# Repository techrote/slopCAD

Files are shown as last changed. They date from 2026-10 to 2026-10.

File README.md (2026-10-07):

# slopCAD

A small collection of practical CAD experiments and 3D-printable workshop parts.

## Contents

- [Hex bit stand](projects/hex-bit-stand/) — compact organizers for 1/4-inch hex bits, developed through several iterations.
  - [v1 — 16-pocket grid](projects/hex-bit-stand/v1-grid-16/)
  - [v2 — 13-pocket hex pattern](projects/hex-bit-stand/v2-hex-pattern-13/)
  - [v3 — 13-pocket contoured body](projects/hex-bit-stand/v3-contoured-13/)
  - [v4 — dense 51-pocket stand](projects/hex-bit-stand/v4-dense-51/) — high-capacity version
  - [v5 — dense contoured 13-pocket stand](projects/hex-bit-stand/v5-dense-contoured-13/) — compact vertical-pocket version
  - [v6 — outward-tilted dense 13-pocket stand](projects/hex-bit-stand/v6-outward-tilted-13/) — 12 outer pockets splayed 10°
  - [v7 — material-efficient dense 51-pocket stand](projects/hex-bit-stand/v7-material-efficient-51/) — relieved pocket floors and tapered wall panels
  - [v8 — tiered-tilt 19-pocket stand](projects/hex-bit-stand/v8-tiered-tilt-19/) — centre vertical, inner ring 4°, outer ring 8°
  - [v9 — effect-plate tiered-tilt 19-pocket stand](projects/hex-bit-stand/v9-effect-plate-19/) — universal misaligned chamfers, inset wall panels, and round floor reliefs
  - [v10 — tapered-hex-floor effect-plate 19-pocket stand](projects/hex-bit-stand/v10-effect-plate-hex-floor-19/) — corrected centre lead-in and 55° tapered hex floor reliefs
  - [v11 — tiered-tilt 37-pocket stand](projects/hex-bit-stand/v11-tiered-tilt-37/) — adds an 18-pocket outer ring at 12°
  - [v12 — clean-wall tiered-tilt 37-pocket stand](projects/hex-bit-stand/v12-clean-wall-37/) — convex 24-face shell removes short-facet triangular print artifacts
  - [v13 — lip-edge panel 37-pocket stand](projects/hex-bit-stand/v13-lip-edge-panels-37/) — wall recesses run directly down to the lower lip
  - [v14 — tiered-tilt 61-pocket stand](projects/hex-bit-stand/v14-tiered-tilt-61/) — historical misaligned-mouth 16° outer-ring experiment
  - [v15 — continuous-web 61-pocket stand](projects/hex-bit-stand/v15-continuous-web-61/) — aligned entrances, measured 1.3 mm minimum surface-web rule and test coupon
  - [v16 — continuous-web 91-pocket stand](projects/hex-bit-stand/v16-continuous-web-91/) — adds a 30-pocket 20° ring; 9.45 mm pitch
  - [v17 — continuous-web 127-pocket stand](projects/hex-bit-stand/v17-continuous-web-127/) — adds a 36-pocket 24° ring; 9.65 mm pitch
  - [v18 — continuous-web 169-pocket stand](projects/hex-bit-stand/v18-continuous-web-169/) — adds a 42-pocket 28° ring; 9.90 mm pitch
  - [v19 — continuous-web 217-pocket stand](projects/hex-bit-stand/v19-continuous-web-217/) — adds a 48-pocket 32° ring; 10.20 mm pitch
  - [v20 — continuous-web 271-pocket stand](projects/hex-bit-stand/v20-continuous-web-271/) — adds a 54-pocket 36° ring; 10.55 mm pitch and wider outer wall
- [Hex handles](project/hex-handles/) — compact five-rib tool handles with deep hex-shaft reinforcement, epoxy retention pockets, and tail venting.
  - [v1 — 32 mm five-rib angular handle](project/hex-handles/v1-32mm-five-rib/) — 6.4 mm AF socket for a nominal 26 mm embedded hex shaft
- [Hex bit stand design history](docs/hex-bit-stand-design-history.md)
- [Current printing and minimum-feature rules](docs/printing.md)
- [Hex handle design history](docs/hex-handles-design-history.md)
- [Hex handle printing and installation notes](docs/hex-handles-printing.md)

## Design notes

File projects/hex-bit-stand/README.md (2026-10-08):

# Hex bit stand

A family of workshop organizers for standard 1/4-inch hex driver bits, developed through printed prototypes.

## Current design target

Functional pockets are **7.0 mm AF normal to the bit axis**, with **12 mm main pocket depth** and a **0.6 mm nozzle** as the primary FDM target. New top/bottom faces must retain **at least 1.3 mm of actual solid ligament** after all cuts, projections and chamfers. Read [the current design/printing rules](../../docs/printing.md); historical thin-web variants are not certified against this newer minimum.

## Versions

| Version | Capacity | Layout | Main change |
|---|---:|---|---|
| [v1](v1-grid-16/) | 16 | 4 × 4 grid | Initial rectangular stand |
| [v2](v2-hex-pattern-13/) | 13 | 4–5–4 | Staggered hex-pocket layout and 1 mm base |
| [v3](v3-contoured-13/) | 13 | 4–5–4 | Body follows the pocket cluster; faceted outer-wall styling |
| [v4](v4-dense-51/) | 51 | 6–7–8–9–8–7–6 | Dense honeycomb packing and high capacity |
| [v5](v5-dense-contoured-13/) | 13 | dense 4–5–4 | Compact v3-style stand using v4 pocket spacing and softened lower lip |
| [v6](v6-outward-tilted-13/) | 13 | dense 4–5–4 | Centre pocket vertical; 12 outer pockets tilted 10° outward |
| [v7](v7-material-efficient-51/) | 51 | 6–7–8–9–8–7–6 | 5.6 mm floor reliefs plus individual 50° tapered outer-wall panels |
| [v8](v8-tiered-tilt-19/) | 19 | radius-2 hex | Centre vertical; 6 inner pockets at 4° and 12 outer pockets at 8°; larger misaligned chamfers |
| [v9](v9-effect-plate-19/) | 19 | radius-2 hex | Universal misaligned chamfers, inset wall panels, and round floor reliefs |
| [v10](v10-effect-plate-hex-floor-19/) | 19 | radius-2 hex | Corrected centre lead-in; 2 mm base with 55° tapered hex floor reliefs |
| [v11](v11-tiered-tilt-37/) | 37 | radius-3 hex | Adds an 18-pocket outer ring tilted 12° outward |
| [v12](v12-clean-wall-37/) | 37 | radius-3 hex | Convex clean-wall shell removes short-facet triangular artifacts |
| [v13](v13-lip-edge-panels-37/) | 37 | radius-3 hex | Wall recesses extend to the lower lip |
| [v14](v14-tiered-tilt-61/) | 61 | radius-4 hex | Historical 16° outer-ring / misaligned-mouth experiment; first-layer pinch points found |
| [v15](v15-continuous-web-61/) | 61 | radius-4 hex | Aligned mouths/shaft roll, 9.3 mm pitch, measured 1.424 mm top web and exported-mesh validation |
| [v16](v16-continuous-web-91/) | 91 | radius-5 hex | Adds 30 pockets at 20°; pitch 9.45 mm; measured 1.433 mm minimum top web |
| [v17](v17-continuous-web-127/) | 127 | radius-6 hex | Adds 36 pockets at 24°; pitch 9.65 mm; measured 1.450 mm minimum top web |
| [v18](v18-continuous-web-169/) | 169 | radius-7 hex | Adds 42 pockets at 28°; pitch 9.90 mm; measured 1.472 mm minimum top web |
| [v19](v19-continuous-web-217/) | 217 | radius-8 hex | Adds 48 pockets at 32°; pitch 10.20 mm; measured 1.493 mm minimum top web |
| [v20](v20-continuous-web-271/) | 271 | radius-9 hex | Adds 54 pockets at 36°; pitch 10.55 mm, 4.1 mm wall margin; measured 1.505 mm minimum top web |

**v15 established the continuous-web production rule and was subsequently physically printed successfully. v16–v20 extend that same aligned-mouth architecture ring by ring through 36°, with pitch increased only as required to keep actual exposed-surface ligaments above 1.3 mm. v20 is the largest prepared/published variant at 271 pockets.** v13 remains the 37-pocket historical lineage; v10 the compact effect-plate lineage; v4/v7 the high-capacity vertical lineage.

Earlier contoured designs received a taller lower lip and 0.4 mm bottom-edge chamfer. Each version folder contains its source, printable STL and notes. Prior printed success does not automatically certify a variant against newly introduced manufacturing rules.

## Original bundles and supplementary tools

The v15–v20 sources and upright models were already published; v15 also includes its validator and requirements, and v16–v20 include compact validation summaries. The original bundles below add the original face-down exports, representative coupons, fuller reports and each version's own supporting tools and evidence. Existing source and STL files remain unchanged.

| Version | Original ZIP | Matched source, tools and fuller evidence | Coupon |
|---|---|---|---:|
| v15 | [hex_bit_stand_v15_bundle.zip](https://github.com/techrote/slopCAD/blob/787cfcae9664eae1e94f732b54b8df4c9cdaca3e/checkpoints/hex-bit-stand/v15-v20/e4b17e6a741fa9f4/originals/hex_bit_stand_v15_bund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) | [Original bundle files](https://github.com/techrote/slopCAD/tree/787cfcae9664eae1e94f732b54b8df4c9cdaca3e/checkpoints/hex-bit-stand/v15-v20/e4b17e6a741fa9f4/unpacked/v15); [full geometry report](https://github.com/techrote/slopCAD/blob/787cfcae9664eae1e94f732b54b8df4c9cdaca3e/checkpoints/hex-bit-stand/v15-v20/e4b17e6a741fa9f4/unpacked/v15/validation.json) | 9 pockets |
| v16 | [hex_bit_stand_v16_91_pocket_bundle.zip](https://github.com/techrote/slopCAD/blob/787cfcae9664eae1e94f732b54b8df4c9cdaca3e/checkpoints/hex-bit-stand/v15-v20/e4b17e6a741fa9f4/originals/hex_bit_stand_v16_91_p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) | [Original bundle files](https://github.com/techrote/slopCAD/tree/787cfcae9664eae1e94f732b54b8df4c9cdaca3e/checkpoints/hex-bit-stand/v15-v20/e4b17e6a741fa9f4/unpacked/v16/hex_bit_stand_conti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); [full geometry report](https://github.com/techrote/slopCAD/blob/787cfcae9664eae1e94f732b54b8df4c9cdaca3e/checkpoints/hex-bit-stand/v15-v20/e4b17e6a741fa9f4/unpacked/v16/hex_bit_stand_conti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) | 11 pockets |
| v17 | [hex_bit_stand_v17_127_pocket_bundle.zip](https://github.com/techrote/slopCAD/blob/787cfcae9664eae1e94f732b54b8df4c9cdaca3e/checkpoints/hex-bit-stand/v15-v20/e4b17e6a741fa9f4/originals/hex_bit_stand_v17_127_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) | [Original bundle files](https://github.com/techrote/slopCAD/tree/787cfcae9664eae1e94f732b54b8df4c9cdaca3e/checkpoints/hex-bit-stand/v15-v20/e4b17e6a741fa9f4/unpacked/v17/hex_bit_stand_conti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); [full geometry report](https://github.com/techrote/slopCAD/blob/787cfcae9664eae1e94f732b54b8df4c9cdaca3e/checkpoints/hex-bit-stand/v15-v20/e4b17e6a741fa9f4/unpacked/v17/hex_bit_stand_conti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) | 13 pockets |
| v18 | [hex_bit_stand_v18_169_pocket_bundle.zip](https://github.com/techrote/slopCAD/blob/787cfcae9664eae1e94f732b54b8df4c9cdaca3e/checkpoints/hex-bit-stand/v15-v20/e4b17e6a741fa9f4/originals/hex_bit_stand_v18_169_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) | [Original bundle files](https://github.com/techrote/slopCAD/tree/787cfcae9664eae1e94f732b54b8df4c9cdaca3e/checkpoints/hex-bit-stand/v15-v20/e4b17e6a741fa9f4/unpacked/v18/hex_bit_stand_conti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); [full geometry report](https://github.com/techrote/slopCAD/blob/787cfcae9664eae1e94f732b54b8df4c9cdaca3e/checkpoints/hex-bit-stand/v15-v20/e4b17e6a741fa9f4/unpacked/v18/hex_bit_stand_conti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) | 15 pockets |
| v19 | [hex_bit_stand_v19_217_pocket_bundle.zip](https://github.com/techrote/slopCAD/blob/787cfcae9664eae1e94f732b54b8df4c9cdaca3e/checkpoints/hex-bit-stand/v15-v20/e4b17e6a741fa9f4/originals/hex_bit_stand_v19_217_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) | [Original bundle files](https://github.com/techrote/slopCAD/tree/787cfcae9664eae1e94f732b54b8df4c9cdaca3e/checkpoints/hex-bit-stand/v15-v20/e4b17e6a741fa9f4/unpacked/v19/hex_bit_stand_conti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); [full geometry report](https://github.com/techrote/slopCAD/blob/787cfcae9664eae1e94f732b54b8df4c9cdaca3e/checkpoints/hex-bit-stand/v15-v20/e4b17e6a741fa9f4/unpacked/v19/hex_bit_stand_conti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) | 17 pockets |
| v20 | [hex_bit_stand_v20_271_pocket_bundle.zip](https://github.com/techrote/slopCAD/blob/787cfcae9664eae1e94f732b54b8df4c9cdaca3e/checkpoints/hex-bit-stand/v15-v20/e4b17e6a741fa9f4/originals/hex_bit_stand_v20_271_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) | [Original bundle files](https://github.com/techrote/slopCAD/tree/787cfcae9664eae1e94f732b54b8df4c9cdaca3e/checkpoints/hex-bit-stand/v15-v20/e4b17e6a741fa9f4/unpacked/v20/hex_bit_stand_conti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); [full geometry report](https://github.com/techrote/slopCAD/blob/787cfcae9664eae1e94f732b54b8df4c9cdaca3e/checkpoints/hex-bit-stand/v15-v20/e4b17e6a741fa9f4/unpacked/v20/hex_bit_stand_conti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) | 19 pockets |

Read the [preservation record](https://github.com/techrote/slopCAD/blob/787cfcae9664eae1e94f732b54b8df4c9cdaca3e/checkpoints/hex-bit-stand/v15-v20/e4b17e6a741fa9f4/PRESERVATION.md) for exact identities, original manifests and source lineage. The original v15–v19 ZIP hashes match values recorded inside later original bundles; v20's ZIP SHA-256 was newly observed during preservation because no earlier expected digest was recovered. Original previews and ZIPs are preserved in this historical checkpoint under the owner's explicit archive request; this does not change active repository illustrations.

### Use one complete archived toolset at a time

Download the required version's original ZIP and extract a **separate writable copy**. v15 is a flat ZIP: its extraction directory is the working directory. For v16–v20, enter the single `hex_bit_stand_continuous_web_<pocket-count>_v<version>/` directory inside the extraction. Each version's original README and scripts belong with that version's source, meshes and metadata. The published upright STLs have different byte identities from the original bundle STLs; preservation neither replaces them nor claims a semantic mesh equivalence or difference.

Use Python with that bundle's `requirements-validation.txt`; keep the Python environment **outside** the bundle directory. v15 requires NumPy 2.3.5, Shapely 2.1.2, Trimesh 4.11.1, NetworkX `>=3.4,<4` and SciPy `>=1.14,<2`. v16–v20 pin the first three versions and NetworkX 3.6.1. OpenSCAD is a separate dependency for rebuilding: the later bundles record OpenSCAD 2021.01 and Python 3.13.5 as the original tested environment.

The version-specific READMEs document the commands and working directories. `validate.py` inspects the matched saved mesh and writes `validation.json`; v16–v20 also include `validate_exports.py` and `build.py`. The build helpers overwrite exports, reports and checksums, so they belong in the writable copy. `check_spacing.py` in v17–v20 and `check_margin.py` in v20 render temporary negative controls and update their reports. OpenSCAD must be on PATH or selected through the relevant tool's `--openscad` option. The v17–v20 preview helper also requires Pillow (the original notes record 12.3.0), which is not in the validation requirements; rendering needs a graphical display or `xvfb-run` on headless Linux. No preview command is needed to access the preserved images.

These commands were reviewed statically for their existing inputs, dependencies and output locations; the historical bundle studies were not rerun to create replacement evidence. Original measurements remain bounded software/geometry evidence. The separately recorded v15 print history does not establish physical acceptance of v16–v20 or certify other historical variants against a later manufacturing rule.

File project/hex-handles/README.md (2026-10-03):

# Hex handles

A family of compact 3D-printable handles for nominal **1/4-inch (6.35 mm) hex-to-hex extension shafts**.

The design direction comes from earlier hand-made/mesh-finished handles and the concept artwork below: chunky angular geometry, broad ribs, pronounced collars, and a short body reinforced by the metal shaft through most of its length.

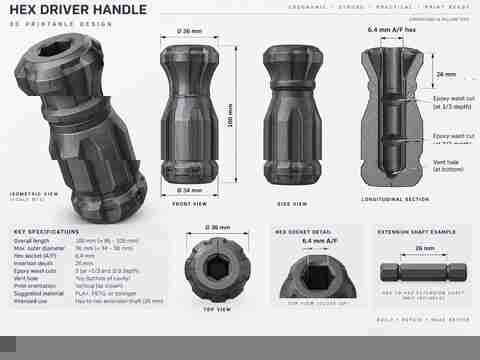
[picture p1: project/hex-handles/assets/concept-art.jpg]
Hex handle concept artwork


## Design target

- **32 mm maximum overall handle length**
- nominal **26 mm metal shaft** embedded through most of the handle
- **6.4 mm flat-to-flat** CAD socket for a nominal 1/4-inch hex shaft
- two internal epoxy reservoirs at approximately **1/3 and 2/3 socket depth**
- continuous tail vent so trapped air and displaced adhesive can escape during assembly
- print with the **hex opening on the build plate**
- support-free geometry designed around a printer capable of approximately **65° overhangs from vertical**
- strong, broad, angular grip features rather than rounded cosmetic fillets
- fine surface texture intentionally omitted from CAD so it can be applied later as a mesh modifier

## Versions

| Version | Length | Ribs | Main change |
|---|---:|---:|---|
| [v1 — 32 mm five-rib angular handle](v1-32mm-five-rib/) | 32 mm | 5 | First accepted design: hard-edged five-rib body, deep 26 mm shaft reinforcement, epoxy reservoirs, and tail vent |

## Current design

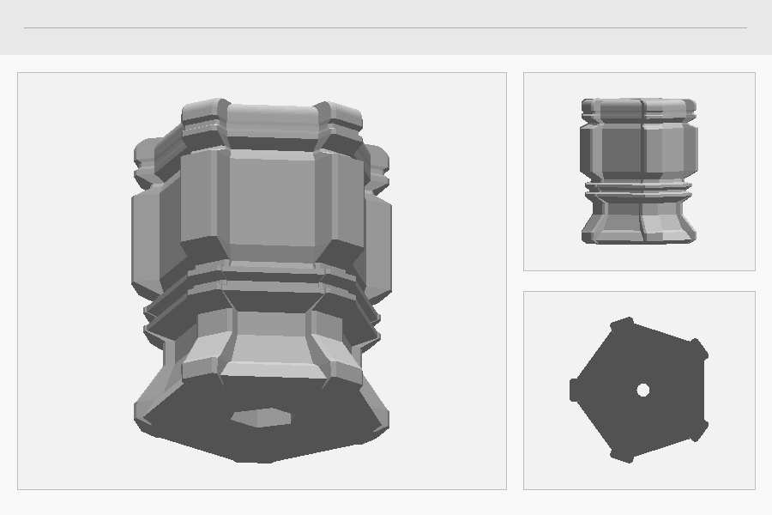
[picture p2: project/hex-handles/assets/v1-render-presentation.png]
V1 render presentation generated from the committed STL


*The V1 presentation above is rendered directly from the committed STL; the concept artwork remains the styling reference.*

The concept art is a styling reference rather than a dimensional drawing. The accepted V1 deliberately compresses the idea into a much shorter body so the metal extension shaft reinforces roughly **81% of the handle length**.

See also:

- [Design history](../../docs/hex-handles-design-history.md)
- [Printing and installation notes](../../docs/hex-handles-printing.md)

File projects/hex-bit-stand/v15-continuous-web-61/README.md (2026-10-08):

# v15 — continuous-web 61-pocket stand

A first-layer reliability revision of v14, based on the owner's sliced and printed representative section. The intended effect-plate orientation is **top face down**.

## Preserved original bundle

The source and upright STL are already published in this project directory, alongside its validator and requirements. [Original ZIP](https://github.com/techrote/slopCAD/blob/787cfcae9664eae1e94f732b54b8df4c9cdaca3e/checkpoints/hex-bit-stand/v15-v20/e4b17e6a741fa9f4/originals/hex_bit_stand_v15_bund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) and the [matched source, tools and evidence](https://github.com/techrote/slopCAD/tree/787cfcae9664eae1e94f732b54b8df4c9cdaca3e/checkpoints/hex-bit-stand/v15-v20/e4b17e6a741fa9f4/unpacked/v15) preserve the complete original package separately.

- [Original full face-down STL](https://github.com/techrote/slopCAD/blob/787cfcae9664eae1e94f732b54b8df4c9cdaca3e/checkpoints/hex-bit-stand/v15-v20/e4b17e6a741fa9f4/unpacked/v15/hex_bit_stand_conti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); [9-pocket face-down coupon](https://github.com/techrote/slopCAD/blob/787cfcae9664eae1e94f732b54b8df4c9cdaca3e/checkpoints/hex-bit-stand/v15-v20/e4b17e6a741fa9f4/unpacked/v15/v15_nine_pocket_tes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); [full historical geometry report](https://github.com/techrote/slopCAD/blob/787cfcae9664eae1e94f732b54b8df4c9cdaca3e/checkpoints/hex-bit-stand/v15-v20/e4b17e6a741fa9f4/unpacked/v15/validation.json).
- [Family archive index and tool-use instructions](../README.md#original-bundles-and-supplementary-tools).

Measurements, validation outcomes, preview-inspection statements and toolchain versions below are historical records from the original bundle. They do not describe new executions during preservation or establish a new slice, physical print or fit result.

## What changed

The deliberately misaligned mouth chamfers are removed. Every entrance follows its own shaft without a rotational step or a scalloped union of two differently rotated cutters. Shaft hexes now share the lattice-aligned orientation before tilting; they no longer acquire an extra tangential rotation around the stand. The actual axis angles remain **0° / 4° / 8° / 12° / 16°**.

Pitch increases from **9.0 to 9.3 mm**, keeping the useful **8.5 mm mouth** rather than shrinking the entrances. Functional shaft size remains **7.0 mm AF normal to the shaft axis**. The aligned mouths are horizontal intersections of those tilted profiles, so their on-bed outline is slightly stretched radially.

The new design rule is **at least 1.3 mm of actual solid ligament on the top and bottom surfaces**. This is an in-plane material-width requirement, not permission to use 1.3 mm nominal pitch-minus-AF when rotations or projections make the real gap smaller. A demonstrated 0.5 mm extrusion width is not evidence that a 0.5 mm exposed junction will form a reliable finish.

The v14 STL's narrowest top-face gap measured about **0.024 mm**. Simply aligning a chamfer to the previous radially rotated shaft would not resolve every vertex-to-vertex bottleneck. Aligning the shaft roll with the lattice is part of this correction.

## Dimensions and retained features

| Feature | v15 |
|---|---|
| Capacity | 61: 1 centre + 6 + 12 + 18 + 24 |
| Tilt bands | 0° / 4° / 8° / 12° / 16° |
| Shaft AF, perpendicular to axis | 7.0 mm |
| Floor-centre pitch | 9.3 mm |
| Aligned mouth AF, perpendicular-profile equivalent | 8.5 mm |
| Mouth chamfer height | 1.15 mm |
| Main pocket vertical depth | 12.0 mm |
| Structural base zone | 2.0 mm |
| Floor transition | 1 mm downward taper, 55° from vertical, then hex exit |
| Nominal centre exit AF | 4.144 mm |
| Overall envelope | 96.35 × 87.70 × 14.00 mm |
| Nominal outer-wall margin | 3.8 mm (was 3.6 mm) |
| Side-panel top/side reference-plane borders | 1.3 mm (were 1.0 mm) |
| Side panels | 1.2 mm depth; 50° side/top taper; open to the lower lip |

The convex wall and softened lower lip remain. Panel positions are derived from the current parameters, rather than a hard-coded perimeter. Width changes must be revalidated; simple assertions are not a substitute for measuring the exported geometry.

## Historical measured validation

Measurements are from the exported STL, not only from source dimensions.

| Check | Result |
|---|---:|
| Minimum top-face inter-pocket web | **1.424 mm** |
| Minimum top-face pocket-to-outer-edge material | **2.399 mm** |
| Minimum underside inter-exit web | **4.937 mm** |
| Minimum underside exit-to-outer-edge material | **6.037 mm** |
| Additional horizontal sections checked | **83** |
| Pockets independently checked for tilt and normal-axis AF | **61** |
| Watertight, positive-volume connected components | **1** |
| Through-hole topology | 61 holes; Euler characteristic −120 |

Both exposed surfaces remain connected after erosion by half the minimum web width (0.65 mm). Every sampled section also passes the 1.3 mm inter-pocket and exterior-wall clearance checks. The normal-axis AF check independently confirms that the 7 mm bit fit was not enlarged or shrunk to obtain clearance.

CAD solid volume is about **49.86 cm³**, versus **44.60 cm³** for the supplied v14 STL: approximately **11.8% more solid-model volume**. Actual filament consumption is slicer-dependent. This is an intentional trade for wider continuous face-down junctions.

**Historical bundle result: geometric validation passed; the original note still required a slicer preview and physical print.** The [family history](../README.md) subsequently records successful physical printing of v15. That existing record is not a new print or fit assessment performed by this preservation task, and does not establish that every seam or extrusion artifact has been eliminated.

## Export and test

Run these existing project commands from `projects/hex-bit-stand/v15-continuous-web-61/`. For the original archived source and meshes, use a separate writable extraction of the flat v15 ZIP as described in the family archive index.

The default source/STL orientation is upright for inspection. For the effect-plate export:

```sh
openscad -D 'print_face_down=true' -o v15_face_down.stl hex_bit_stand_continuous_web_61_v15.scad
```

A nine-pocket coupon uses the exact production pocket positions and all five tilt bands, including the narrowest ring-3/ring-4 pair and adjacent three-pocket junctions. Its outside is simplified and does not test the full side-panel treatment:

```sh
openscad -D 'export_part="coupon"' -D 'print_face_down=true' -o v15_test_face_down.stl hex_bit_stand_continuous_web_61_v15.scad
```

To rebuild and validate the full upright mesh:

```sh
python -m pip install -r requirements-validation.txt
openscad -o hex_bit_stand_continuous_web_61_v15.stl hex_bit_stand_continuous_web_61_v15.scad
python validate.py
```

`validate.py` exits nonzero for inadequate surface webs, a disconnected thin-web core, missing/intersecting pockets, incorrect tilt/AF or invalid mesh topology. It writes a detailed `validation.json`. GitHub Actions runs this geometry check independently of the STL-regeneration workflow.

## Files

- `hex_bit_stand_continuous_web_61_v15.scad` — self-contained parameterised source, including coupon/orientation options.
- `hex_bit_stand_continuous_web_61_v15.stl` — full upright mesh.
- `validate.py` — exported-mesh surface, section, tilt and fit checks.
- `requirements-validation.txt` — validation dependencies.

See the [current printing/design rules](../../../docs/printing.md). Older revisions remain historical and are not retroactively certified against the 1.3 mm rule.

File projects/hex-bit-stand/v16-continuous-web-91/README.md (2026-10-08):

# v16 — continuous-web 91-pocket bit stand

An expansion of the physically successful **v15 continuous-web 61-pocket stand**. It adds one complete ring without reverting to the earlier misaligned/scalloped entrances.

**Ready-to-print orientation:** the source supports `print_face_down=true` for effect-plate printing.

## Preserved original bundle

The source and upright STL are already published in this project directory, alongside the compact validation summary. [Original ZIP](https://github.com/techrote/slopCAD/blob/787cfcae9664eae1e94f732b54b8df4c9cdaca3e/checkpoints/hex-bit-stand/v15-v20/e4b17e6a741fa9f4/originals/hex_bit_stand_v16_91_p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) and the [matched source, tools and evidence](https://github.com/techrote/slopCAD/tree/787cfcae9664eae1e94f732b54b8df4c9cdaca3e/checkpoints/hex-bit-stand/v15-v20/e4b17e6a741fa9f4/unpacked/v16/hex_bit_stand_conti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) preserve the complete original package separately.

- [Original full face-down STL](https://github.com/techrote/slopCAD/blob/787cfcae9664eae1e94f732b54b8df4c9cdaca3e/checkpoints/hex-bit-stand/v15-v20/e4b17e6a741fa9f4/unpacked/v16/hex_bit_stand_conti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); [11-pocket face-down coupon](https://github.com/techrote/slopCAD/blob/787cfcae9664eae1e94f732b54b8df4c9cdaca3e/checkpoints/hex-bit-stand/v15-v20/e4b17e6a741fa9f4/unpacked/v16/hex_bit_stand_conti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); [full historical geometry report](https://github.com/techrote/slopCAD/blob/787cfcae9664eae1e94f732b54b8df4c9cdaca3e/checkpoints/hex-bit-stand/v15-v20/e4b17e6a741fa9f4/unpacked/v16/hex_bit_stand_conti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).
- [Family archive index and tool-use instructions](../README.md#original-bundles-and-supplementary-tools).

Measurements, validation outcomes, preview-inspection statements and toolchain versions below are historical records from the original bundle. They do not describe new executions during preservation or establish a new slice, physical print or fit result.

## Pocket layout

| Band | Pockets | Outward tilt |
|---|---:|---:|
| Centre | 1 | 0° |
| Ring 1 | 6 | 4° |
| Ring 2 | 12 | 8° |
| Ring 3 | 18 | 12° |
| Ring 4 | 24 | 16° |
| **New ring 5** | **30** | **20°** |
| **Total** | **91** | |

The new outer axes shift **4.368 mm radially outward** between the main pocket floor and the top face.

## Spacing

With the old **9.30 mm** pitch, the extra 20° ring produces a minimum exported top-face web of only **1.283 mm**, below the required 1.3 mm. The printable v16 therefore uses **9.45 mm** pitch.

The v16 exported mesh measures **1.433 mm** at the tightest top junction. Chamfers follow the shaft phase continuously, with no intentional rotational mismatch.

## Dimensions and retained geometry

| Feature | v16 |
|---|---|
| Overall envelope, upright | **118.025 × 106.630 × 14.00 mm** |
| Functional shaft size, perpendicular to its axis | **7.0 mm flat-to-flat** |
| Floor-centre pitch | **9.45 mm** |
| Aligned mouth profile, normal-axis AF equivalent | **8.5 mm** |
| Mouth lead-in height | **1.15 mm** |
| Main pocket vertical depth | **12.0 mm** |
| Structural base zone | **2.0 mm** |
| Floor transition | **1 mm downward, 55° from vertical, then a hex exit** |
| Nominal centre underside exit | **4.144 mm AF** |
| Nominal outer-wall margin | **3.8 mm** |
| Side-panel top/side reference-plane borders | **1.3 mm** |
| Side panels | **1.2 mm recess, 50° side/top taper, open to the lower lip** |
| Bottom-edge chamfer | **0.4 mm** |

The **1.3 mm minimum top/bottom material-width rule remains in force**. It refers to actual in-plane solid ligaments and surface connectivity after cuts, not simply nominal pitch minus flat-to-flat size.

## Historical exported-mesh validation

| Check | Result |
|---|---:|
| Minimum top-face inter-pocket web | **1.433 mm** |
| Minimum top-face opening-to-outer-edge material | **2.285 mm** |
| Minimum underside inter-exit web | **4.941 mm** |
| Minimum underside exit-to-outer-edge material | **5.953 mm** |
| Additional horizontal sections checked | **83** |
| Pockets checked for angle, radial direction, position and normal-axis AF | **91** |
| Watertight positive-volume connected components | **1** |
| Through-hole topology | **91 holes; Euler characteristic −180** |

Both exposed surfaces and all sampled sections remain connected after erosion by **0.65 mm**, half the required minimum width.

**Scope:** geometric validation only. The owner's physical success report applies to v15; v16 was not physically accepted when prepared.

## Files

- [hex_bit_stand_continuous_web_91_v16.scad](hex_bit_stand_continuous_web_91_v16.scad) — self-contained parametric source.
- [hex_bit_stand_continuous_web_91_v16.stl](hex_bit_stand_continuous_web_91_v16.stl) — canonical upright STL generated from the source.
- [validation_summary.json](validation_summary.json) — compact measured validation record.

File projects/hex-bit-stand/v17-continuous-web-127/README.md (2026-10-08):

# v17 — continuous-web 127-pocket stand

Expansion of the actual v16 91-pocket model. The new sixth ring contains **36 pockets tilted 24° radially outward**.

## Preserved original bundle

The source and upright STL are already published in this project directory, alongside the compact validation summary. [Original ZIP](https://github.com/techrote/slopCAD/blob/787cfcae9664eae1e94f732b54b8df4c9cdaca3e/checkpoints/hex-bit-stand/v15-v20/e4b17e6a741fa9f4/originals/hex_bit_stand_v17_127_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) and the [matched source, tools and evidence](https://github.com/techrote/slopCAD/tree/787cfcae9664eae1e94f732b54b8df4c9cdaca3e/checkpoints/hex-bit-stand/v15-v20/e4b17e6a741fa9f4/unpacked/v17/hex_bit_stand_conti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) preserve the complete original package separately.

- [Original full face-down STL](https://github.com/techrote/slopCAD/blob/787cfcae9664eae1e94f732b54b8df4c9cdaca3e/checkpoints/hex-bit-stand/v15-v20/e4b17e6a741fa9f4/unpacked/v17/hex_bit_stand_conti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); [13-pocket face-down coupon](https://github.com/techrote/slopCAD/blob/787cfcae9664eae1e94f732b54b8df4c9cdaca3e/checkpoints/hex-bit-stand/v15-v20/e4b17e6a741fa9f4/unpacked/v17/hex_bit_stand_conti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); [full historical geometry report](https://github.com/techrote/slopCAD/blob/787cfcae9664eae1e94f732b54b8df4c9cdaca3e/checkpoints/hex-bit-stand/v15-v20/e4b17e6a741fa9f4/unpacked/v17/hex_bit_stand_conti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).
- [Family archive index and tool-use instructions](../README.md#original-bundles-and-supplementary-tools).

Measurements, validation outcomes, preview-inspection statements and toolchain versions below are historical records from the original bundle. They do not describe new executions during preservation or establish a new slice, physical print or fit result.

## Download / print orientation

**Use [hex_bit_stand_continuous_web_127_v17_face_down.stl](https://github.com/techrote/slopCAD/blob/787cfcae9664eae1e94f732b54b8df4c9cdaca3e/checkpoints/hex-bit-stand/v15-v20/e4b17e6a741fa9f4/unpacked/v17/hex_bit_stand_conti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) for effect-plate printing.** It is already rotated with the normal pocket-opening face on the bed at Z = 0. Do not flip it again. Its maximum envelope is **140.98 × 126.78 × 14.00 mm**, before any slicer brim or skirt.

[hex_bit_stand_continuous_web_127_v17.stl](https://github.com/techrote/slopCAD/blob/787cfcae9664eae1e94f732b54b8df4c9cdaca3e/checkpoints/hex-bit-stand/v15-v20/e4b17e6a741fa9f4/unpacked/v17/hex_bit_stand_conti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) is the identical part in its upright/use orientation for inspection. The SCAD defaults to that upright orientation.

[v17_thirteen_pocket_test_face_down.stl](https://github.com/techrote/slopCAD/blob/787cfcae9664eae1e94f732b54b8df4c9cdaca3e/checkpoints/hex-bit-stand/v15-v20/e4b17e6a741fa9f4/unpacked/v17/hex_bit_stand_conti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) is a smaller, **already face-down** test section. It contains all seven tilt bands, the narrowest 20°/24° pair, and adjacent three-pocket junctions at the exact production coordinates. The exterior is simplified; this coupon does not validate the complete side-wall panel treatment. Its envelope is **76.14 × 23.03 × 14.00 mm**.

## Layout and dimensions

| Band | Pocket count | Outward tilt |
|---|---:|---:|
| Centre | 1 | 0° |
| Ring 1 | 6 | 4° |
| Ring 2 | 12 | 8° |
| Ring 3 | 18 | 12° |
| Ring 4 | 24 | 16° |
| Ring 5 | 30 | 20° |
| New ring 6 | 36 | 24° |
| Total | 127 | |

| Feature | v17 |
|---|---|
| Floor-centre pitch | **9.65 mm**, increased from 9.45 mm |
| Functional shaft fit | **7.0 mm AF normal to the tilted axis** |
| Aligned mouth profile | **8.5 mm AF before horizontal-plane projection** |
| Mouth chamfer vertical height | **1.15 mm**, unchanged |
| Main pocket vertical depth | **12.0 mm**, unchanged |
| Structural base zone | **2.0 mm**, unchanged |
| Floor transition | **1 mm downward / 55° from vertical**, then a hex through-exit |
| Nominal centre exit size | **4.144 mm AF** |
| New outer axis displacement | **5.343 mm outward** over the 12 mm vertical pocket height |
| Outer-wall margin | **3.8 mm**, unchanged |
| Side-panel top/side reference-plane border | **1.3 mm**, unchanged |
| Side panels | **1.2 mm recess / 50° side and top taper**, open to the lower lip |
| Lower lip | Previous softened lip and **0.4 mm lower-edge chamfer** retained |

The main pockets still use the v15/v16 lattice-aligned roll and minimal rotation from vertical. There is **no deliberately misaligned entrance**. Pocket and mouth outlines remain aligned with one another, including on the new ring. Because a tilted prism intersects a horizontal plane obliquely, its on-bed hex is slightly elongated; the normal-axis bit fit is not enlarged to produce clearance.

## Why the spacing changes

With six rings at the old **9.45 mm pitch**, the exported negative-control mesh has only **1.250 mm** at its narrowest top-face junction. The 1.3 mm validator rejects that mesh. Merely adding a new ring at the old pitch would therefore repeat the under-width problem.

A 9.55 mm pitch would clear 1.3 mm only narrowly (about 1.350 mm analytically). The selected **9.65 mm** pitch instead produces an exported gap of **1.450 mm**, retaining a margin comparable to v15/v16 rather than targeting the exact threshold. Existing pocket angles remain unchanged; their floor centres move slightly because the pitch increases uniformly.

The surface rule remains **at least 1.3 mm of actual in-plane solid material between openings and at the outside rim**, after projections, offsets and Boolean operations. Nominal pitch minus AF is not an adequate substitute for measuring the model. This rule does not forbid a chamfer from terminating in an edge; it applies to finite material webs and rims, not the mathematical edge of a taper.

## Historical exported geometry checks

Results below are measured on the supplied **upright STL**. The binary face-down export is separately checked against every vertex of the rigidly rotated upright mesh.

| Check | Result |
|---|---:|
| Minimum top-face inter-pocket web | **1.450 mm** |
| Minimum top-face opening-to-exterior material | **2.131 mm** |
| Minimum underside inter-exit web | **4.950 mm** |
| Minimum underside exit-to-exterior material | **5.847 mm** |
| Additional horizontal sections checked | **83** |
| Pockets independently checked for position, outward direction, tilt and normal-axis AF | **127** |
| Connected watertight positive-volume solids | **1** |
| Through-holes | **127**, Euler characteristic **−252** |
| Maximum face-down vertex difference after rotation / float32 export | **0.0000036 mm** |
| Maximum coupon/full-model hole-outline difference across 11 depths | **0.0000594 mm** |

Both exposed surfaces and all 83 sampled sections remain connected after their boundaries are eroded by **0.65 mm** (half the minimum width). Every sampled section also clears the inter-opening and exterior-wall width checks. This is a set of measured section checks, not a formal proof over every possible cross-section.

The aligned entrance bevels were also measured directly: their steepest face-down overhang is approximately **49.22° from vertical** (vertical wall = 0°, horizontal unsupported ceiling = 90°). The existing 1.15 mm chamfer height therefore does not need reducing for the 24° ring. This measurement concerns the pocket entrances, not every external lip or side-panel surface.

The CAD solid volume is **102.83 cm³**. Actual filament quantity depends on slicing. The supplied v16 record reports 72.91 cm³; this increase mostly reflects the additional 36 pockets and larger stand, and is not a comparison of material efficiency per pocket under identical geometry.

**All listed geometric checks passed. v17 has not been sliced with the owner's printer profile or physically printed here.** The coupon provides a smaller first-layer and new-angle trial; geometric clearance does not eliminate all seam, extrusion or adhesion artifacts.

## Build and validate

These are commands for the **complete original bundle**, not this reduced project directory. Download the original ZIP linked above, extract it into a separate writable working area, and use `hex_bit_stand_continuous_web_127_v17/` as the working directory. Keep the archived source, tools, metadata and meshes together; do not combine them with a different published STL. Keep the Python environment outside that bundle directory: the build helper includes other local files in its checksum walk. The original toolchain versions and commands follow; they were inspected for paths and dependencies during preservation, not rerun as historical validation.

Tested with **OpenSCAD 2021.01**, Python **3.13.5**, NumPy **2.3.5**, Shapely **2.1.2**, Trimesh **4.11.1**, and NetworkX **3.6.1**. OpenSCAD is a separate system dependency; Python packages are pinned in [requirements-validation.txt](https://github.com/techrote/slopCAD/blob/787cfcae9664eae1e94f732b54b8df4c9cdaca3e/checkpoints/hex-bit-stand/v15-v20/e4b17e6a741fa9f4/unpacked/v17/hex_bit_stand_conti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).

```sh
python -m pip install -r requirements-validation.txt
python build.py
```

On Windows, point to the console executable when it is not on PATH:

```powershell
python build.py --openscad "C:\Program Files\OpenSCAD\openscad.com"
```

The build exports the full upright part, derives the exact face-down rigid transform, exports the face-down coupon, runs the mesh and export validators, and refreshes the validation records and file manifest. Each subprocess has an explicit timeout. It does not regenerate previews or narrative documentation.

To rerun the independent spacing sweep and intentionally undersized exported-mesh control:

```sh
python check_spacing.py
```

The negative control is created in a temporary directory and never overwrites the production models. Its expected failure is `FAIL: top web < 1.3 mm`.

Direct OpenSCAD exports are also supported:

```sh
openscad -o v17_upright.stl hex_bit_stand_continuous_web_127_v17.scad
openscad -D 'print_face_down=true' -o v17_face_down.stl hex_bit_stand_continuous_web_127_v17.scad
openscad -D 'export_part="coupon"' -D 'print_face_down=true' -o v17_coupon.stl hex_bit_stand_continuous_web_127_v17.scad
```

[render_previews.py](https://github.com/techrote/slopCAD/blob/787cfcae9664eae1e94f732b54b8df4c9cdaca3e/checkpoints/hex-bit-stand/v15-v20/e4b17e6a741fa9f4/unpacked/v17/hex_bit_stand_conti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) produces exact STL previews through OpenSCAD. It additionally requires Pillow (tested **12.3.0**) and uses `xvfb-run` when available on headless Linux. It only crops the renderer's uniform background; no geometry or appearance is invented.

## Package contents and integrity

The package contains both full-model orientations, the test coupon, standalone SCAD source, build/validation tools, previews, [validation.json](https://github.com/techrote/slopCAD/blob/787cfcae9664eae1e94f732b54b8df4c9cdaca3e/checkpoints/hex-bit-stand/v15-v20/e4b17e6a741fa9f4/unpacked/v17/hex_bit_stand_conti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), [validation_summary.json](https://github.com/techrote/slopCAD/blob/787cfcae9664eae1e94f732b54b8df4c9cdaca3e/checkpoints/hex-bit-stand/v15-v20/e4b17e6a741fa9f4/unpacked/v17/hex_bit_stand_conti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), [export_validation.json](https://github.com/techrote/slopCAD/blob/787cfcae9664eae1e94f732b54b8df4c9cdaca3e/checkpoints/hex-bit-stand/v15-v20/e4b17e6a741fa9f4/unpacked/v17/hex_bit_stand_conti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), [spacing_checks.json](https://github.com/techrote/slopCAD/blob/787cfcae9664eae1e94f732b54b8df4c9cdaca3e/checkpoints/hex-bit-stand/v15-v20/e4b17e6a741fa9f4/unpacked/v17/hex_bit_stand_conti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), [regression_checks.json](https://github.com/techrote/slopCAD/blob/787cfcae9664eae1e94f732b54b8df4c9cdaca3e/checkpoints/hex-bit-stand/v15-v20/e4b17e6a741fa9f4/unpacked/v17/hex_bit_stand_conti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), provenance, and publication notes. [evidence/source_changes.patch](https://github.com/techrote/slopCAD/blob/787cfcae9664eae1e94f732b54b8df4c9cdaca3e/checkpoints/hex-bit-stand/v15-v20/e4b17e6a741fa9f4/unpacked/v17/hex_bit_stand_conti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) records the narrow geometry change from the verified v16 source.

[SHA256SUMS](https://github.com/techrote/slopCAD/blob/787cfcae9664eae1e94f732b54b8df4c9cdaca3e/checkpoints/hex-bit-stand/v15-v20/e4b17e6a741fa9f4/unpacked/v17/hex_bit_stand_conti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) records supplied file bytes. Rebuilding with OpenSCAD may change STL triangle ordering and therefore byte hashes without changing the part; the geometric validator should be rerun and the manifest refreshed. Archive identities and their historical or newly observed provenance are recorded in the family archive index and preservation manifest.

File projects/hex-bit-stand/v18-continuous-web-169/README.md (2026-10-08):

# v18 — continuous-web 169-pocket stand

Expansion of the actual v17 127-pocket model. The new seventh ring contains **42 pockets tilted 28° radially outward**.

## Preserved original bundle

The source and upright STL are already published in this project directory, alongside the compact validation summary. [Original ZIP](https://github.com/techrote/slopCAD/blob/787cfcae9664eae1e94f732b54b8df4c9cdaca3e/checkpoints/hex-bit-stand/v15-v20/e4b17e6a741fa9f4/originals/hex_bit_stand_v18_169_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) and the [matched source, tools and evidence](https://github.com/techrote/slopCAD/tree/787cfcae9664eae1e94f732b54b8df4c9cdaca3e/checkpoints/hex-bit-stand/v15-v20/e4b17e6a741fa9f4/unpacked/v18/hex_bit_stand_conti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) preserve the complete original package separately.

- [Original full face-down STL](https://github.com/techrote/slopCAD/blob/787cfcae9664eae1e94f732b54b8df4c9cdaca3e/checkpoints/hex-bit-stand/v15-v20/e4b17e6a741fa9f4/unpacked/v18/hex_bit_stand_conti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); [15-pocket face-down coupon](https://github.com/techrote/slopCAD/blob/787cfcae9664eae1e94f732b54b8df4c9cdaca3e/checkpoints/hex-bit-stand/v15-v20/e4b17e6a741fa9f4/unpacked/v18/hex_bit_stand_conti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); [full historical geometry report](https://github.com/techrote/slopCAD/blob/787cfcae9664eae1e94f732b54b8df4c9cdaca3e/checkpoints/hex-bit-stand/v15-v20/e4b17e6a741fa9f4/unpacked/v18/hex_bit_stand_conti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).
- [Family archive index and tool-use instructions](../README.md#original-bundles-and-supplementary-tools).

Measurements, validation outcomes, preview-inspection statements and toolchain versions below are historical records from the original bundle. They do not describe new executions during preservation or establish a new slice, physical print or fit result.

## Print files and orientation

**Use [hex_bit_stand_continuous_web_169_v18_face_down.stl](https://github.com/techrote/slopCAD/blob/787cfcae9664eae1e94f732b54b8df4c9cdaca3e/checkpoints/hex-bit-stand/v15-v20/e4b17e6a741fa9f4/unpacked/v18/hex_bit_stand_conti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) for effect-plate printing.** It is already rotated so the normal pocket-opening face is on the bed at Z = 0. Do not flip it again. The maximum envelope is **165.55 × 148.26 × 14.00 mm**, before any slicer brim or skirt.

[hex_bit_stand_continuous_web_169_v18.stl](https://github.com/techrote/slopCAD/blob/787cfcae9664eae1e94f732b54b8df4c9cdaca3e/checkpoints/hex-bit-stand/v15-v20/e4b17e6a741fa9f4/unpacked/v18/hex_bit_stand_conti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) is the identical part in its upright/use orientation for inspection. The SCAD defaults to that upright orientation.

[v18_fifteen_pocket_test_face_down.stl](https://github.com/techrote/slopCAD/blob/787cfcae9664eae1e94f732b54b8df4c9cdaca3e/checkpoints/hex-bit-stand/v15-v20/e4b17e6a741fa9f4/unpacked/v18/hex_bit_stand_conti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) is a smaller, **already face-down** test section. It contains all eight tilt bands, a symmetry-equivalent instance of the narrowest 24°/28° pair, and adjacent three-pocket junctions at the exact production coordinates. Its exterior is simplified; it does not validate the complete side-wall panel treatment. Its envelope is approximately **88.74 × 23.24 × 14.00 mm**.

## Geometry

| Location | Pockets | Outward tilt from vertical |
|---|---:|---:|
| Centre | 1 | 0° |
| Ring 1 | 6 | 4° |
| Ring 2 | 12 | 8° |
| Ring 3 | 18 | 12° |
| Ring 4 | 24 | 16° |
| Ring 5 | 30 | 20° |
| Ring 6 | 36 | 24° |
| New ring 7 | 42 | 28° |
| Total | **169** | |

The 28° outer axes move **6.381 mm radially outward** from their centre positions at the pocket floor to the top, over 12 mm of vertical height.

| Feature | v18 |
|---|---|
| Functional hex size, measured perpendicular to its axis | **7.0 mm AF** |
| Floor-centre lattice pitch | **9.90 mm** |
| Aligned entrance profile size, before horizontal projection | **8.5 mm AF** |
| Entrance chamfer vertical height | **1.15 mm** |
| Main pocket vertical depth | **12.0 mm** |
| Base zone thickness | **2.0 mm** |
| Floor transition | 1 mm downward taper, **55° from vertical**, then smaller hex exit |
| Nominal vertical-centre exit AF | **4.144 mm** |
| Nominal outer-wall margin | **3.8 mm** |
| Side-panel reference-plane top/side borders | **1.3 mm** |
| Side-panel depth and taper | **1.2 mm**, **50°**; open down to the lower lip |
| Bottom-edge chamfer | **0.4 mm** |

The aligned entrance and shaft share the same phase; the former rotationally misaligned/scalloped entrance treatment is **not** reintroduced. All shafts retain the lattice-aligned roll before their outward tilt. A horizontal cut through a tilted pocket is slightly stretched radially, so 7 mm and 8.5 mm are not statements of horizontal AF in every direction.

The convex wall, softened lower lip, lip-edge side recesses, 2 mm base and tapered hex exits are retained from v17. The only changes to the main source parameters are ring count, the additional tilt-band value, and pitch. The coupon selection expands accordingly.

## Why pitch increased

Adding the 28° ring at v17's **9.65 mm** spacing would leave a narrowest top-face web of only **1.222 mm**. That violates the **1.3 mm minimum actual top/bottom surface-ligament rule**.

Pitch is therefore increased to **9.90 mm**, which gives a measured top-face web of **1.472 mm**. This preserves a useful margin rather than barely clearing the limit. Pocket sizes are not shrunk to obtain it.

The rule concerns in-plane solid material remaining after all cuts and tilted projections, not nominal pitch minus AF. It is separate from the retained 2 mm base zone and the 1 mm-tall straight exit section.

An independent analytical sweep checked 9.65, 9.75, 9.80, 9.85, 9.90 and 9.95 mm. A deliberately underspaced, fully rendered 9.65 mm model was rejected by the same mesh validator with `FAIL: top web < 1.3 mm`. Only the temporary source's pitch guard was relaxed; the minimum-width measurement rule remained enabled. That negative control never replaced the production models.

## Historical measured geometric validation

These are measurements of the exported upright STL, not just source dimensions:

| Check | Result |
|---|---:|
| Minimum top-face inter-pocket web | **1.472 mm** |
| Minimum top opening to exterior material | **1.948 mm** |
| Minimum underside inter-exit web | **4.961 mm** |
| Minimum underside exit to exterior material | **5.714 mm** |
| Additional horizontal sections checked | **83** |
| Minimum exterior-wall clearance across those sections | **1.891 mm** |
| Pockets independently checked for position, outward direction, tilt and normal-axis AF | **169** |
| Connected watertight positive-volume solids | **1** |
| Through-holes | **169**, Euler characteristic **−336** |
| Maximum face-down vertex difference after rotation / float32 export | **0.0000039 mm** |
| Maximum coupon/full-model hole-outline difference across 11 depths | **0.0000582 mm** |

Both exposed surfaces and all 83 sampled sections remain connected after their boundaries are eroded inward by **0.65 mm**, half the minimum web width. Every sampled section also passes the inter-opening and exterior-wall clearance checks. These sampled section checks are not a formal proof over every possible cross-section.

The steepest measured entrance-chamfer face, when printing face down, is **51.79° from vertical** (vertical wall = 0°; unsupported horizontal ceiling = 90°). This remains below the previously supplied 60° soft limit, so the 1.15 mm chamfer height does not need reducing for the 28° ring. This check concerns entrance faces only, not every external side-panel or lip surface.

CAD solid volume is **141.68 cm³**. Actual filament quantity depends on slicing. The verified supplied v17 record reports 102.83 cm³; the increase reflects another 42 pockets, wider spacing and the larger body, rather than a same-capacity efficiency comparison.

**All listed geometric checks passed. v18 has not been sliced with the owner's printer profile or physically printed here.** Geometric clearance does not guarantee seam placement, adhesion, surface quality or extrusion continuity in a particular slicer profile.

## Rebuild and validate

These are commands for the **complete original bundle**, not this reduced project directory. Download the original ZIP linked above, extract it into a separate writable working area, and use `hex_bit_stand_continuous_web_169_v18/` as the working directory. Keep the archived source, tools, metadata and meshes together; do not combine them with a different published STL. Keep the Python environment outside that bundle directory: the build helper includes other local files in its checksum walk. The original toolchain versions and commands follow; they were inspected for paths and dependencies during preservation, not rerun as historical validation.

Environment used: **OpenSCAD 2021.01**, Python **3.13.5**, NumPy **2.3.5**, Shapely **2.1.2**, Trimesh **4.11.1**, NetworkX **3.6.1**. OpenSCAD is a separate system dependency; the Python validation dependencies are pinned in [requirements-validation.txt](https://github.com/techrote/slopCAD/blob/787cfcae9664eae1e94f732b54b8df4c9cdaca3e/checkpoints/hex-bit-stand/v15-v20/e4b17e6a741fa9f4/unpacked/v18/hex_bit_stand_conti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).

```sh
python -m pip install -r requirements-validation.txt
python build.py
```

On Windows, supply the console executable when it is not on PATH:

```powershell
python build.py --openscad "C:\Program Files\OpenSCAD\openscad.com"
```

The build helper exports the upright model, derives its exact face-down rigid transform, exports the coupon, runs the mesh and export validators, and refreshes [validation_summary.json](https://github.com/techrote/slopCAD/blob/787cfcae9664eae1e94f732b54b8df4c9cdaca3e/checkpoints/hex-bit-stand/v15-v20/e4b17e6a741fa9f4/unpacked/v18/hex_bit_stand_conti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) and the file manifest. Each subprocess has an explicit timeout. It does not regenerate narrative documentation, baseline provenance, regression comparison records or preview images.

The build steps can also be checked separately:

```sh
python validate.py
python validate_exports.py
python check_spacing.py
```

The spacing check renders its negative control in a temporary directory and does not overwrite production models. Direct SCAD exports are also available:

```sh
openscad -o v18_upright.stl hex_bit_stand_continuous_web_169_v18.scad
openscad -D 'print_face_down=true' -o v18_face_down.stl hex_bit_stand_continuous_web_169_v18.scad
openscad -D 'export_part="coupon"' -D 'print_face_down=true' -o v18_coupon.stl hex_bit_stand_continuous_web_169_v18.scad
```

[render_previews.py](https://github.com/techrote/slopCAD/blob/787cfcae9664eae1e94f732b54b8df4c9cdaca3e/checkpoints/hex-bit-stand/v15-v20/e4b17e6a741fa9f4/unpacked/v18/hex_bit_stand_conti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) renders the actual STL using OpenSCAD. It additionally requires Pillow (tested **12.3.0**) and uses `xvfb-run` when available on headless Linux. It only crops the uniform background; no geometry is invented or altered for the previews.

## Package contents and integrity

The package contains both full-model orientations, the coupon, standalone SCAD, build/validation tools, exact-mesh previews, full and summary validation records, export checks, spacing checks, regression comparisons, provenance and later-publication notes.

The actual v17 packet was verified before derivation: all **29** entries in its [v17 SHA256SUMS](https://github.com/techrote/slopCAD/blob/787cfcae9664eae1e94f732b54b8df4c9cdaca3e/checkpoints/hex-bit-stand/v15-v20/e4b17e6a741fa9f4/unpacked/v17/hex_bit_stand_conti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) matched, and the eight corresponding mounted attachments matched the packet bytes. [evidence/source_changes.patch](https://github.com/techrote/slopCAD/blob/787cfcae9664eae1e94f732b54b8df4c9cdaca3e/checkpoints/hex-bit-stand/v15-v20/e4b17e6a741fa9f4/unpacked/v18/hex_bit_stand_conti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) records this revision against that verified v17 source. The seven functional geometry modules were checked unchanged; the data now selects seven rings instead of six.

[SHA256SUMS](https://github.com/techrote/slopCAD/blob/787cfcae9664eae1e94f732b54b8df4c9cdaca3e/checkpoints/hex-bit-stand/v15-v20/e4b17e6a741fa9f4/unpacked/v18/hex_bit_stand_conti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) records all supplied file bytes except itself. Rebuilding may change STL triangle ordering and byte hashes without changing geometry; rerun the geometry validators and refresh hashes. Archive identities and their historical or newly observed provenance are recorded in the family archive index and preservation manifest.

The source, upright STL and summary are published in this project. The complete original bundle is now preserved at the immutable archive linked above; original local-only preparation statements remain unchanged inside that archive.

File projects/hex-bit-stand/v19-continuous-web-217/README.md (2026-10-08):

# v19 — continuous-web 217-pocket stand

Expansion of the verified v18 169-pocket model. The new eighth ring contains **48 pockets tilted 32° radially outward**.

## Preserved original bundle

The source and upright STL are already published in this project directory, alongside the compact validation summary. [Original ZIP](https://github.com/techrote/slopCAD/blob/787cfcae9664eae1e94f732b54b8df4c9cdaca3e/checkpoints/hex-bit-stand/v15-v20/e4b17e6a741fa9f4/originals/hex_bit_stand_v19_217_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) and the [matched source, tools and evidence](https://github.com/techrote/slopCAD/tree/787cfcae9664eae1e94f732b54b8df4c9cdaca3e/checkpoints/hex-bit-stand/v15-v20/e4b17e6a741fa9f4/unpacked/v19/hex_bit_stand_conti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) preserve the complete original package separately.

- [Original full face-down STL](https://github.com/techrote/slopCAD/blob/787cfcae9664eae1e94f732b54b8df4c9cdaca3e/checkpoints/hex-bit-stand/v15-v20/e4b17e6a741fa9f4/unpacked/v19/hex_bit_stand_conti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); [17-pocket face-down coupon](https://github.com/techrote/slopCAD/blob/787cfcae9664eae1e94f732b54b8df4c9cdaca3e/checkpoints/hex-bit-stand/v15-v20/e4b17e6a741fa9f4/unpacked/v19/hex_bit_stand_conti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); [full historical geometry report](https://github.com/techrote/slopCAD/blob/787cfcae9664eae1e94f732b54b8df4c9cdaca3e/checkpoints/hex-bit-stand/v15-v20/e4b17e6a741fa9f4/unpacked/v19/hex_bit_stand_conti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).
- [Family archive index and tool-use instructions](../README.md#original-bundles-and-supplementary-tools).

Measurements, validation outcomes, preview-inspection statements and toolchain versions below are historical records from the original bundle. They do not describe new executions during preservation or establish a new slice, physical print or fit result.

## Print files and orientation

**Use [hex_bit_stand_continuous_web_217_v19_face_down.stl](https://github.com/techrote/slopCAD/blob/787cfcae9664eae1e94f732b54b8df4c9cdaca3e/checkpoints/hex-bit-stand/v15-v20/e4b17e6a741fa9f4/unpacked/v19/hex_bit_stand_conti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) for effect-plate printing.** It is already rotated so the normal pocket-opening face sits on the bed at Z = 0. Do not flip it again. Its maximum envelope is **192.05 × 171.50 × 14.00 mm**, before any slicer skirt or brim; check the available bed area including those additions.

[hex_bit_stand_continuous_web_217_v19.stl](https://github.com/techrote/slopCAD/blob/787cfcae9664eae1e94f732b54b8df4c9cdaca3e/checkpoints/hex-bit-stand/v15-v20/e4b17e6a741fa9f4/unpacked/v19/hex_bit_stand_conti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) is the identical part in upright/use orientation for inspection. The SCAD defaults to that orientation.

[v19_seventeen_pocket_test_face_down.stl](https://github.com/techrote/slopCAD/blob/787cfcae9664eae1e94f732b54b8df4c9cdaca3e/checkpoints/hex-bit-stand/v15-v20/e4b17e6a741fa9f4/unpacked/v19/hex_bit_stand_conti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) is the **already face-down** test coupon. It contains all nine tilt bands, a symmetry-equivalent tightest 28°/32° pair, and adjacent three-pocket junctions at the exact production coordinates. Its exterior is simplified and does not validate the complete side-panel treatment. The coupon measures **102.36 × 23.52 × 14.00 mm** and has approximately **21.61 cm³** CAD solid volume.

## Geometry

| Location | Pockets | Outward tilt from vertical |
|---|---:|---:|
| Centre | 1 | 0° |
| Ring 1 | 6 | 4° |
| Ring 2 | 12 | 8° |
| Ring 3 | 18 | 12° |
| Ring 4 | 24 | 16° |
| Ring 5 | 30 | 20° |
| Ring 6 | 36 | 24° |
| Ring 7 | 42 | 28° |
| New ring 8 | 48 | 32° |
| Total | **217** | |

The new outer axes move **7.498 mm radially outward** from their pocket-floor centres to the top over 12 mm of vertical height. All earlier rings retain their tilt angles.

| Feature | v19 |
|---|---|
| Functional hex, measured perpendicular to its axis | **7.0 mm AF** |
| Floor-centre lattice pitch | **10.20 mm** |
| Aligned entrance equivalent profile, before horizontal projection | **8.5 mm AF** |
| Entrance chamfer vertical height | **1.15 mm** |
| Main pocket vertical depth | **12.0 mm** |
| Base zone thickness | **2.0 mm** |
| Floor transition | **1 mm / 55° from vertical**, then smaller hex through-exit |
| Nominal centre exit AF | **4.144 mm** |
| Nominal outer-wall margin | **3.8 mm** |
| Side-panel reference-plane top/side borders | **1.3 mm** |
| Side-panel depth and taper | **1.2 mm / 50°**, open down to the lower lip |
| Bottom-edge chamfer | **0.4 mm** |

The aligned entrance and shaft retain the same phase. The former rotationally misaligned/scalloped chamfers are **not** reintroduced. The shaft roll is lattice-aligned before tilting; a horizontal slice is stretched radially, so 7 mm and 8.5 mm are not horizontal AF dimensions in every direction.

The convex wall, softened lower lip, lip-edge side recesses, base and tapered hex exits are inherited from v18. The only primary parameter changes are ring count, one additional tilt band and pitch. The coupon selection expands from 15 to 17 pockets. Seven geometry-generating modules are byte-for-byte unchanged from the verified v18 source; see [regression_checks.json](https://github.com/techrote/slopCAD/blob/787cfcae9664eae1e94f732b54b8df4c9cdaca3e/checkpoints/hex-bit-stand/v15-v20/e4b17e6a741fa9f4/unpacked/v19/hex_bit_stand_conti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).

## Why pitch increased

Adding the 32° ring at the previous **9.90 mm pitch** would leave a narrowest top-face web of only **1.193 mm**. This fails the **1.3 mm minimum actual top/bottom surface-width rule**.

Pitch is increased to **10.20 mm**, giving **1.493 mm** measured web. The entrances are not shrunk. This maintains a useful margin above the minimum instead of barely passing it.

The rule is the actual in-plane material remaining after cuts and tilted projections, not nominal pitch-minus-AF. It is separate from the retained 2 mm base zone and the 1 mm-tall straight exit section.

An independent analytical sweep checked 9.90, 10.00, 10.05, 10.10, 10.15, 10.20 and 10.25 mm pitch. A completely rendered temporary 9.90 mm model was rejected by the same mesh validator with `FAIL: top web < 1.3 mm`. Only its source pitch guard was relaxed; the minimum-width rule stayed enabled. This negative control never replaced the production files.

## Historical measured geometric validation

Measurements below are from the exported upright STL:

| Check | Result |
|---|---:|
| Minimum top-face inter-pocket web | **1.493 mm** |
| Minimum top opening to outside edge | **1.714 mm** |
| Minimum underside inter-exit web | **4.965 mm** |
| Minimum underside exit to outside edge | **5.551 mm** |
| Additional horizontal sections checked | **83** |
| Minimum exterior-wall clearance across sampled sections | **1.551 mm** |
| Pockets checked for position, direction, tilt and normal-axis AF | **217** |
| Connected watertight positive-volume solids | **1** |
| Through-holes / Euler characteristic | **217 / −432** |
| Maximum tilt measurement error | **0.000259°** |
| Maximum normal-axis AF error | **0.0000859 mm** |
| Face-down vertex difference after rotation and binary export | **0.0000038 mm** |
| Maximum coupon/full-model hole-outline difference over 11 depths | **0.0000625 mm** |

Both exposed surfaces and all 83 sampled sections remain connected after their boundaries are eroded inward by **0.65 mm**, half the minimum web width. Every sampled section passes the inter-opening and exterior-wall clearance checks. These sampled checks are not a formal proof over every possible cross-section.

The steepest measured entrance-chamfer face is **54.35° from vertical** in the face-down print orientation: vertical wall = 0°, unsupported horizontal ceiling = 90°. This remains below the supplied 60° soft limit, so the chamfer height needs no reduction. The measurement covers entrance faces only, not every side-panel or lip surface.

CAD solid volume is **192.06 cm³**. The verified supplied v18 report gives **141.68 cm³**; the difference includes 48 additional pockets, wider spacing and a larger body, and is not a same-capacity efficiency comparison. Filament quantity depends on the slicer settings.

**All listed geometric checks passed. v19 has not been sliced with the owner's printer profile or physically printed here.** Geometry checks do not guarantee seam placement, adhesion, surface finish or continuous extrusion with a particular printer/slicer profile.

## Rebuild and validate

These are commands for the **complete original bundle**, not this reduced project directory. Download the original ZIP linked above, extract it into a separate writable working area, and use `hex_bit_stand_continuous_web_217_v19/` as the working directory. Keep the archived source, tools, metadata and meshes together; do not combine them with a different published STL. Keep the Python environment outside that bundle directory: the build helper includes other local files in its checksum walk. The original toolchain versions and commands follow; they were inspected for paths and dependencies during preservation, not rerun as historical validation.

Tested environment: **OpenSCAD version 2021.01**, Python **3.13.5**, NumPy **2.3.5**, Shapely **2.1.2**, Trimesh **4.11.1**, NetworkX **3.6.1**. OpenSCAD is a separate dependency; the Python validator dependencies are pinned in [requirements-validation.txt](https://github.com/techrote/slopCAD/blob/787cfcae9664eae1e94f732b54b8df4c9cdaca3e/checkpoints/hex-bit-stand/v15-v20/e4b17e6a741fa9f4/unpacked/v19/hex_bit_stand_conti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).

```sh
python -m pip install -r requirements-validation.txt
python build.py
```

On Windows, supply the console executable when it is not on PATH:

```powershell
python build.py --openscad "C:\Program Files\OpenSCAD\openscad.com"
```

The build helper exports the upright model, derives the face-down rigid transform, exports the coupon, runs the mesh/export validators and refreshes [validation_summary.json](https://github.com/techrote/slopCAD/blob/787cfcae9664eae1e94f732b54b8df4c9cdaca3e/checkpoints/hex-bit-stand/v15-v20/e4b17e6a741fa9f4/unpacked/v19/hex_bit_stand_conti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) and [SHA256SUMS](https://github.com/techrote/slopCAD/blob/787cfcae9664eae1e94f732b54b8df4c9cdaca3e/checkpoints/hex-bit-stand/v15-v20/e4b17e6a741fa9f4/unpacked/v19/hex_bit_stand_conti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). Each subprocess has a timeout. It does not regenerate narrative documentation, baseline provenance, regression records, spacing checks or previews.

Separate checks:

```sh
python validate.py
python validate_exports.py
python check_spacing.py
```

The spacing check uses a temporary directory for its negative control and leaves the production models untouched. Direct OpenSCAD exports:

```sh
openscad -o v19_upright.stl hex_bit_stand_continuous_web_217_v19.scad
openscad -D 'print_face_down=true' -o v19_face_down.stl hex_bit_stand_continuous_web_217_v19.scad
openscad -D 'export_part="coupon"' -D 'print_face_down=true' -o v19_coupon.stl hex_bit_stand_continuous_web_217_v19.scad
```

[render_previews.py](https://github.com/techrote/slopCAD/blob/787cfcae9664eae1e94f732b54b8df4c9cdaca3e/checkpoints/hex-bit-stand/v15-v20/e4b17e6a741fa9f4/unpacked/v19/hex_bit_stand_conti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) renders the actual upright STL using OpenSCAD. It additionally requires Pillow (tested **12.3.0**) and uses `xvfb-run` on headless Linux when available. It only crops uniform background; no geometry is fabricated for the previews. The perspective, top and underside previews were visually inspected.

## Package and integrity

The package contains both full-model orientations, the coupon, standalone SCAD, build and validation tools, exact-STL previews, full/summary validation records, export and spacing checks, regression/provenance records and later-publication notes.

Before derivation, all **32 entries** in the actual v18 packet's [v18 SHA256SUMS](https://github.com/techrote/slopCAD/blob/787cfcae9664eae1e94f732b54b8df4c9cdaca3e/checkpoints/hex-bit-stand/v15-v20/e4b17e6a741fa9f4/unpacked/v18/hex_bit_stand_conti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) were verified. Its **9 corresponding mounted attachments** also matched the packet bytes. [evidence/source_changes.patch](https://github.com/techrote/slopCAD/blob/787cfcae9664eae1e94f732b54b8df4c9cdaca3e/checkpoints/hex-bit-stand/v15-v20/e4b17e6a741fa9f4/unpacked/v19/hex_bit_stand_conti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) records the minimal SCAD changes against that verified baseline.

[SHA256SUMS](https://github.com/techrote/slopCAD/blob/787cfcae9664eae1e94f732b54b8df4c9cdaca3e/checkpoints/hex-bit-stand/v15-v20/e4b17e6a741fa9f4/unpacked/v19/hex_bit_stand_conti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) covers all supplied files except itself. Rebuilding can change triangle order and file hashes without changing geometry; rerun validators and refresh hashes. Archive identities and their historical or newly observed provenance are recorded in the family archive index and preservation manifest.

The source, upright STL and summary are published in this project. The complete original bundle is now preserved at the immutable archive linked above; original local-only preparation statements remain unchanged inside that archive.

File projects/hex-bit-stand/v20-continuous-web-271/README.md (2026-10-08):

# v20 — continuous-web 271-pocket stand

Expansion of the supplied and hash-verified **v19 continuous-web 217-pocket stand**. This adds a ninth ring containing **54 new pockets at 36° outward**. The aligned entrances, lattice-aligned shaft roll and **1.3 mm actual surface-width requirement** are retained.

## Preserved original bundle

The source and upright STL are already published in this project directory, alongside the compact validation summary. [Original ZIP](https://github.com/techrote/slopCAD/blob/787cfcae9664eae1e94f732b54b8df4c9cdaca3e/checkpoints/hex-bit-stand/v15-v20/e4b17e6a741fa9f4/originals/hex_bit_stand_v20_271_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) and the [matched source, tools and evidence](https://github.com/techrote/slopCAD/tree/787cfcae9664eae1e94f732b54b8df4c9cdaca3e/checkpoints/hex-bit-stand/v15-v20/e4b17e6a741fa9f4/unpacked/v20/hex_bit_stand_conti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) preserve the complete original package separately.

- [Original full face-down STL](https://github.com/techrote/slopCAD/blob/787cfcae9664eae1e94f732b54b8df4c9cdaca3e/checkpoints/hex-bit-stand/v15-v20/e4b17e6a741fa9f4/unpacked/v20/hex_bit_stand_conti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); [19-pocket face-down coupon](https://github.com/techrote/slopCAD/blob/787cfcae9664eae1e94f732b54b8df4c9cdaca3e/checkpoints/hex-bit-stand/v15-v20/e4b17e6a741fa9f4/unpacked/v20/hex_bit_stand_conti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); [full historical geometry report](https://github.com/techrote/slopCAD/blob/787cfcae9664eae1e94f732b54b8df4c9cdaca3e/checkpoints/hex-bit-stand/v15-v20/e4b17e6a741fa9f4/unpacked/v20/hex_bit_stand_conti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).
- [Family archive index and tool-use instructions](../README.md#original-bundles-and-supplementary-tools).

Measurements, validation outcomes, preview-inspection statements and toolchain versions below are historical records from the original bundle. They do not describe new executions during preservation or establish a new slice, physical print or fit result.

## Printable files

- **[hex_bit_stand_continuous_web_271_v20_face_down.stl](https://github.com/techrote/slopCAD/blob/787cfcae9664eae1e94f732b54b8df4c9cdaca3e/checkpoints/hex-bit-stand/v15-v20/e4b17e6a741fa9f4/unpacked/v20/hex_bit_stand_conti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)** — full model already oriented for top-face-down effect-plate printing. Do not flip it again.
- **[v20_nineteen_pocket_test_face_down.stl](https://github.com/techrote/slopCAD/blob/787cfcae9664eae1e94f732b54b8df4c9cdaca3e/checkpoints/hex-bit-stand/v15-v20/e4b17e6a741fa9f4/unpacked/v20/hex_bit_stand_conti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)** — 19-pocket representative coupon, already face-down. It includes all ten tilt bands and a tightest 32°/36° pair with neighbouring three-pocket junctions.
- **[hex_bit_stand_continuous_web_271_v20.stl](https://github.com/techrote/slopCAD/blob/787cfcae9664eae1e94f732b54b8df4c9cdaca3e/checkpoints/hex-bit-stand/v15-v20/e4b17e6a741fa9f4/unpacked/v20/hex_bit_stand_conti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)** — full model in its upright/use orientation for inspection.
- **[hex_bit_stand_continuous_web_271_v20.scad](https://github.com/techrote/slopCAD/blob/787cfcae9664eae1e94f732b54b8df4c9cdaca3e/checkpoints/hex-bit-stand/v15-v20/e4b17e6a741fa9f4/unpacked/v20/hex_bit_stand_conti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)** — standalone editable OpenSCAD source with full-model/coupon and orientation switches.

The coupon uses exact production coordinates and cavities, but a simplified 2 mm exterior rather than the full side-panel treatment. Its envelope is **117.17 × 23.85 × 14.00 mm**. It does not substitute for testing the full stand's side walls or large-bed adhesion.

## Layout and dimensions

| Region | Pockets | Outward tilt |
|---|---:|---:|
| Centre | 1 | 0° |
| Ring 1 | 6 | 4° |
| Ring 2 | 12 | 8° |
| Ring 3 | 18 | 12° |
| Ring 4 | 24 | 16° |
| Ring 5 | 30 | 20° |
| Ring 6 | 36 | 24° |
| Ring 7 | 42 | 28° |
| Ring 8 | 48 | 32° |
| **New ring 9** | **54** | **36°** |
| **Total** | **271** | |

| Feature | v20 |
|---|---|
| Full envelope in supplied orientation | **221.62 × 197.46 × 14.00 mm** |
| Shaft size, normal to its axis | **7.0 mm AF** |
| Floor-centre pitch | **10.55 mm**, increased from 10.20 mm |
| Aligned entrance profile before horizontal projection | **8.5 mm AF** |
| Entrance chamfer vertical height | **1.15 mm** |
| Main pocket vertical depth | **12.0 mm** |
| Base zone | **2.0 mm** |
| Floor transition | **1 mm / 55° from vertical**, then smaller hex through-exit |
| Nominal centre exit AF | **4.144 mm** |
| Nominal outer-wall margin | **4.1 mm**, increased from 3.8 mm |
| Side-panel reference-plane side/top borders | **1.3 mm** |
| Panel recess | **1.2 mm**, with **50°** side/top taper and open to the lower lip |
| Outward reach of side-panel cutting solids | **3.0 mm**, increased from 2.0 mm |
| Lower-edge chamfer | **0.4 mm** |

The new ring axes move **8.719 mm radially outward** over the main pocket height. All prior rings keep their tilt angles; increasing pitch moves their floor centres slightly farther apart. The shaft and entrance dimensions are not reduced to obtain clearance.

The aligned hexes retain the same phase throughout each entrance. A horizontal section is stretched radially by the tilt, so the quoted 7 mm and 8.5 mm profiles are not horizontal AF dimensions in every direction. The discarded rotationally misaligned/scalloped chamfers are not reintroduced.

## Build-plate placement

The full model is **221.62 mm wide in the supplied orientation**, before any skirt or brim. Check the usable print area rather than only a printer's nominal bed size.

A **15° rotation around Z**, keeping the supplied face-down side on the plate, gives a **215.71 × 215.71 mm** bounding rectangle. This is a rigid rotation, not scaling. It may help on a square bed, but does not include clearance for a skirt, brim, clips or excluded bed regions. The measured rotation envelopes are in [placement.json](https://github.com/techrote/slopCAD/blob/787cfcae9664eae1e94f732b54b8df4c9cdaca3e/checkpoints/hex-bit-stand/v15-v20/e4b17e6a741fa9f4/unpacked/v20/hex_bit_stand_conti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).

## Changes needed for the ninth ring

**Spacing.** At v19's 10.20 mm pitch, the new 32°/36° junction measures only **1.155 mm** across its narrowest top web. This fails the 1.3 mm rule. A 10.55 mm pitch gives **1.505 mm**, preserving useful margin without shrinking the entrance. [check_spacing.py](https://github.com/techrote/slopCAD/blob/787cfcae9664eae1e94f732b54b8df4c9cdaca3e/checkpoints/hex-bit-stand/v15-v20/e4b17e6a741fa9f4/unpacked/v20/hex_bit_stand_conti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) compares an independent analytical pitch sweep with the actual mesh and confirms that a rendered old-spacing model is rejected by the same validator.

**Exterior wall.** At the old 3.8 mm outer margin, the extra splay approaches the back of the side recesses too closely: targeted sections measure as little as **1.155 mm**. Increasing the margin to 4.1 mm gives **1.455 mm** at the same targeted sections. [check_margin.py](https://github.com/techrote/slopCAD/blob/787cfcae9664eae1e94f732b54b8df4c9cdaca3e/checkpoints/hex-bit-stand/v15-v20/e4b17e6a741fa9f4/unpacked/v20/hex_bit_stand_conti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) renders and rejects the old-margin control; it leaves production files untouched.

**Cutter reach.** An initial trial retained the old 2 mm outward reach of the side cutters. At 36°, several cutter openings no longer reached beyond the upper part of the splayed shell. Horizontal inspection detected 48 additional enclosed recess outlines at z=10.5 and 10.7 mm. Extending the cutting solids outward to 3 mm removes these thin exterior cover skins without deepening the retained 1.2 mm recess. The final mesh has only the intended 271 pocket holes at every checked section. A source assertion also checks outward reach against the upper-wall displacement.

The rule remains **at least 1.3 mm of actual in-plane material width**, after all cuts and projections. This is distinct from the 2 mm base zone and its 1 mm exit/taper sections. A nominal pitch-minus-AF figure is not used as a substitute for geometry measurements.

## Historical exported-mesh validation

| Measurement | Result |
|---|---:|
| Minimum top-face inter-pocket web | **1.505 mm** |
| Minimum top opening to outside edge | **1.738 mm** |
| Minimum underside inter-exit web | **4.953 mm** |
| Minimum underside exit to outside edge | **5.652 mm** |
| Regular additional horizontal sections | **83** |
| Minimum exterior wall in those sections | **1.458 mm** |
| Additional targeted side-panel sections | **10** |
| Minimum exterior wall in targeted sections | **1.455 mm** |
| Pockets checked for position, outward direction, tilt and normal-axis AF | **271** |
| Connected watertight positive-volume solids | **1** |
| Through-holes / Euler characteristic | **271 / −540** |
| Maximum tilt measurement error | **0.0000114°** |
| Maximum normal-axis AF error | **0.00000477 mm** |
| Maximum face-down transform/export vertex error | **0.000000477 mm** |

Both exposed surfaces and all 83 regular sections remain connected after erosion by **0.65 mm**, half the minimum web width. The validator measures all opening pairs, not just assumed nearest neighbours. These finite sampled checks are not a formal proof over every possible cross-section.

The entrance-chamfer maximum measured overhang is **56.88° from vertical** in the face-down orientation: a vertical face is 0°, an unsupported horizontal ceiling is 90°. It remains below the supplied 60° soft limit, so entrance height is unchanged. This measurement covers the entrance bevels, not all exterior lip/panel surfaces.

The external top rim grows enough at 36° to include a 0.01 mm-tall vertical export cap. The validator now identifies entrance triangles by their full ruled-segment endpoints, so it does not count those unrelated cap faces as entrance bevels. It still requires exactly six triangulated bevels per pocket. All-pairs checks were vectorized without changing the acceptance criteria; scalar/vectorized distances were cross-checked on the supplied v19 mesh.

Seven inherited geometry modules are byte-for-byte unchanged; [regression_checks.json](https://github.com/techrote/slopCAD/blob/787cfcae9664eae1e94f732b54b8df4c9cdaca3e/checkpoints/hex-bit-stand/v15-v20/e4b17e6a741fa9f4/unpacked/v20/hex_bit_stand_conti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) and [evidence/source_changes.patch](https://github.com/techrote/slopCAD/blob/787cfcae9664eae1e94f732b54b8df4c9cdaca3e/checkpoints/hex-bit-stand/v15-v20/e4b17e6a741fa9f4/unpacked/v20/hex_bit_stand_conti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) record the exact source changes. All 271 functional shaft measurements and the coupon/full-model comparisons pass. The coupon cavities match the full mesh over 11 checked heights, including the entrance and hex floor exits.

CAD solid volume is **259.90 cm³**. The supplied v19 volume was 192.06 cm³; the increase includes 54 additional pockets, wider spacing and a larger exterior wall, not a same-capacity efficiency comparison. Filament consumption depends on slicing.

**Geometric checks passed. No v20 printer-profile slicing or physical printing was performed here.** Seam placement, extrusion continuity, effect-plate finish, adhesion and strength still require print testing.

## Rebuild and test

These are commands for the **complete original bundle**, not this reduced project directory. Download the original ZIP linked above, extract it into a separate writable working area, and use `hex_bit_stand_continuous_web_271_v20/` as the working directory. Keep the archived source, tools, metadata and meshes together; do not combine them with a different published STL. Keep the Python environment outside that bundle directory: the build helper includes other local files in its checksum walk. The original toolchain versions and commands follow; they were inspected for paths and dependencies during preservation, not rerun as historical validation.

Tested with OpenSCAD **2021.01**, Python **3.13.5**, NumPy **2.3.5**, Shapely **2.1.2**, Trimesh **4.11.1** and NetworkX **3.6.1**. OpenSCAD is a separate dependency. The Python requirements are pinned in [requirements-validation.txt](https://github.com/techrote/slopCAD/blob/787cfcae9664eae1e94f732b54b8df4c9cdaca3e/checkpoints/hex-bit-stand/v15-v20/e4b17e6a741fa9f4/unpacked/v20/hex_bit_stand_conti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).

```sh
python -m pip install -r requirements-validation.txt
python build.py
python check_spacing.py
python check_margin.py
```

On Windows, supply the OpenSCAD console executable when it is not on PATH:

```powershell
python build.py --openscad "C:\Program Files\OpenSCAD\openscad.com"
```

The build helper exports the full mesh and coupon as **binary STL**, preserving coordinate precision at the larger footprint. It creates the rigidly transformed face-down mesh, runs both geometry/export validators, and refreshes the summary and checksum manifest. Each subprocess has a timeout. It does not regenerate narrative documentation, historical evidence, previews, or spacing/margin controls.

Direct export examples:

```sh
openscad --export-format binstl -o v20_upright.stl hex_bit_stand_continuous_web_271_v20.scad
openscad --export-format binstl -D 'print_face_down=true' -o v20_face_down.stl hex_bit_stand_continuous_web_271_v20.scad
openscad --export-format binstl -D 'export_part="coupon"' -D 'print_face_down=true' -o v20_coupon.stl hex_bit_stand_continuous_web_271_v20.scad
```

[render_previews.py](https://github.com/techrote/slopCAD/blob/787cfcae9664eae1e94f732b54b8df4c9cdaca3e/checkpoints/hex-bit-stand/v15-v20/e4b17e6a741fa9f4/unpacked/v20/hex_bit_stand_conti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) renders the actual upright STL in OpenSCAD and crops only uniform background. It additionally needs Pillow (tested 12.3.0) and uses `xvfb-run` on headless Linux when available. The perspective/top/underside previews were inspected after rendering.

## Provenance and later publication

The actual supplied v19 packet was used, not recreated from a chat description. All **31 checksum entries** in that packet were verified, and **9 corresponding mounted attachments** matched its bytes. These are baseline integrity checks, not a new physical acceptance claim for v19.

The packet contains both full-model orientations, the coupon, source, build/check tools, exact-STL previews, complete and summary geometry reports, negative controls, regression/provenance records and [PUBLICATION_NOTES.md](https://github.com/techrote/slopCAD/blob/787cfcae9664eae1e94f732b54b8df4c9cdaca3e/checkpoints/hex-bit-stand/v15-v20/e4b17e6a741fa9f4/unpacked/v20/hex_bit_stand_conti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).

[SHA256SUMS](https://github.com/techrote/slopCAD/blob/787cfcae9664eae1e94f732b54b8df4c9cdaca3e/checkpoints/hex-bit-stand/v15-v20/e4b17e6a741fa9f4/unpacked/v20/hex_bit_stand_conti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) covers the delivered files other than itself. Archive identities and their historical or newly observed provenance are recorded in the family archive index and preservation manifest. Changes to exports or documentation require refreshing the manifest; triangle order may change after rebuilding without changing geometry.

The source, upright STL and summary are published in this project. The complete original bundle is now preserved at the immutable archive linked above; original local-only preparation statements remain unchanged inside that archive.

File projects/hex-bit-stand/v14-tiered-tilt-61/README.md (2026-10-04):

# v14 — tiered-tilt 61-pocket stand

A radius-4 expansion of `v13-lip-edge-panels-37`.

## Pocket layout

The stand contains **61 pockets** in five tilt bands:

- centre: **0°**
- ring 1 — 6 pockets: **4° outward**
- ring 2 — 12 pockets: **8° outward**
- ring 3 — 18 pockets: **12° outward**
- new ring 4 — 24 pockets: **16° outward**

The new outer ring moves about **3.44 mm radially outward** over the 12 mm pocket depth.
The 9 mm lattice still leaves approximately **1.72 mm of floor-level web** at the
16° ring after accounting for the tilted 7 mm shaft projection.

## Mouth chamfers

The deliberately irregular/misaligned chamfer treatment is retained and pushed a
little further:

- functional shaft hex orientation: **30°**
- global mouth/chamfer hex orientation: **0°**
- the centre pocket therefore has an exact **30° shaft/mouth phase offset**, putting
  the chamfer points on the shaft-flat midlines;
- tilted pockets inherit varying apparent offsets as their shaft frames rotate
  radially around the stand.

The mouth remains **8.5 mm AF**. Chamfer height is fixed at **1.15 mm** rather than
1.2 mm. On the 16° outer ring this limits the steepest radial side of the bed-facing
chamfer to about **69.9° from the build plane**, staying within the agreed ~70°
experimental ceiling while keeping the chamfer visually substantial.

## Effect-plate floor geometry

Carried over unchanged from v10–v13:

- **2.0 mm base**
- pocket bottom tapers inward for **1.0 mm at 55°**
- resulting smaller hex continues through the remaining 1 mm of base
- tilted pockets use the exact horizontal cross-section of their tilted shafts
- suitable for top-face-down printing on carbon/holographic/effect plates

## Outer wall

The v13 clean-wall/open-bottom panel treatment is retained:

- convex outer shell
- **3.6 mm nominal wall margin**
- **30 clean outer-wall faces**
- **1.0 mm side/top panel border**
- **1.2 mm recess depth**
- **50° side/top taper**
- recesses extend directly to the upper edge of the lower lip

The shortest wall face is about **6.77 mm**, still leaving about **1.91 mm of
back-flat** behind a full-depth panel, so no adaptive triangle/gusset geometry is
required.

## Envelope

Approximately **93.55 × 85.22 × 14.0 mm**.

## Validation

The generated STL is a **single connected watertight volume**.

## Files

- `hex_bit_stand_tiered_tilt_61_v14.scad` — parametric OpenSCAD source
- `hex_bit_stand_tiered_tilt_61_v14.stl` — printable mesh

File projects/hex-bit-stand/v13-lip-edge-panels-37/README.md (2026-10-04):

# v13 — lip-edge panel 37-pocket stand

A small side-wall refinement of `v12-clean-wall-37` based on physical-print feedback.

## Change from v12

The 24 recessed outer-wall pockets now extend directly down to the **upper edge of the flared lower lip**.

Previously each recess retained a 1 mm lower border, which left the inset visually floating above the lip. v13 removes that bottom border and the corresponding bottom taper:

- panel opening begins at the lip edge (`z = 2.10 mm`), with a 0.05 mm boolean overlap to prevent a residual shelf;
- **1.0 mm side borders** retained;
- **1.0 mm top border** retained;
- **1.2 mm recess depth** retained;
- **50° side and top taper** retained;
- bottom of the recess is open to the lip edge rather than tapering upward.

This should make each wall cut read as a single pocket rising directly out of the lower lip and eliminate the flat strip underneath the recesses.

## Retained geometry

- **37 pockets**: centre + 6 + 12 + 18
- tilt bands: **0° / 4° / 8° / 12°**
- **7.0 mm AF** functional pockets
- **9.0 mm** pitch
- **1.2 mm / 8.5 mm AF** misaligned mouth chamfers
- **2.0 mm base**
- **1 mm-high / 55°** tapered hex floor reliefs
- corrected centre lead-in
- effect-plate / top-face-down print compatibility
- convex **24-face** clean outer shell
- **3.6 mm** nominal wall margin
- softened lower lip and **0.4 mm** bottom-edge chamfer

## Envelope

Approximately **74.04 × 68.04 × 14.0 mm**.

## Validation

The generated STL is a **single connected watertight volume**.

## Files

- `hex_bit_stand_tiered_tilt_37_v13.scad` — parametric source
- `hex_bit_stand_tiered_tilt_37_v13.stl` — printable mesh

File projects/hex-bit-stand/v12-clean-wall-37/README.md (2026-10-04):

# v12 — clean-wall tiered-tilt 37-pocket stand

A side-wall cleanup of `v11-tiered-tilt-37`, prompted by physical printing of the adaptive short-facet panel geometry.

## What changed

- Pocket layout and tilt remain unchanged: **37 pockets**, with **0° / 4° / 8° / 12°** tilt bands.
- The outer shell no longer follows every shallow notch between outer-ring pockets.
- The pocket envelope is now **convexified before the wall offset**, producing **24 longer, cleaner wall faces** instead of 42 short/alternating facets.
- Nominal outer wall margin increases from **3.0 mm to 3.6 mm**.
- Every wall face now uses the same full **1.2 mm-deep / 50° tapered inset panel**.
- The adaptive short-face depth logic and its narrow triangular residuals are removed entirely.

The shortest new wall face is about **6.78 mm**, leaving about **1.92 mm of back-flat** after the 1 mm borders and full 1.2 mm / 50° taper. There is therefore no need for the small triangular compromise geometry that printed poorly on v11.

## Retained geometry

- **37 pockets**: centre + 6 + 12 + 18
- tilt bands: **0° / 4° / 8° / 12°**
- **7.0 mm AF** functional pockets
- **9.0 mm** pitch
- **1.2 mm / 8.5 mm AF** misaligned mouth chamfers
- **2.0 mm base**
- **1 mm-high / 55°** tapered hex floor reliefs
- corrected centre lead-in
- effect-plate / top-face-down printing support
- softened lower lip and **0.4 mm** lower edge chamfer

## Envelope

Approximately **74.04 × 68.04 × 14.0 mm**.

The cleaner shell adds roughly **5.3% CAD solid volume** versus v11. This is an intentional trade: slightly more material for substantially more printable side-wall geometry.

## Files

- `hex_bit_stand_tiered_tilt_37_v12.scad` — parametric source
- `hex_bit_stand_tiered_tilt_37_v12.stl` — printable mesh

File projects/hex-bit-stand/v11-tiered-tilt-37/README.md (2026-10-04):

# v11 — tiered-tilt 37-pocket effect-plate stand

A radius-3 expansion of `v10-effect-plate-hex-floor-19`.

## Pocket layout

- **37 pockets** total
- centre: **0°**
- 6-pocket ring 1: **4° outward**
- 12-pocket ring 2: **8° outward**
- 18-pocket ring 3: **12° outward**
- pitch: **9.0 mm**
- functional pocket: **7.0 mm AF**
- overall envelope: approximately **72.84 × 67.77 × 14.0 mm**
- footprint aspect ratio: approximately **1.08:1**

The outer 12° ring moves about **2.55 mm radially outward** over the 12 mm pocket height.

## Carried over from v10

- **2.0 mm structural base**
- **1.0 mm-high / 55° inward tapered hex floor transition**
- smaller hexagonal through-hole through the remaining 1 mm of base
- exact horizontal cross-section handling for tilted pocket floors
- corrected centre-pocket lead-in
- enlarged **1.2 mm / 8.5 mm AF** mouth chamfers
- deliberately misaligned/scalloped chamfers on the tilted rings
- no continuous waist groove
- individual **50° tapered wall inset panels**
- softened lower lip and **0.4 mm lower-edge chamfer**
- intended for normal or top-face-down effect-plate printing

## Wall-panel handling

The larger radius-3 contour resolves into **42 outer-wall facets**, including some
shorter than those on v10. Panel recess depth remains **1.2 mm nominal**. On the
shortest facets, depth is reduced only as much as necessary to retain at least a
**0.5 mm back-flat**, matching the demonstrated minimum printable line width.

## Spacing

At the 12° outer ring, the horizontal projection of the 7 mm shaft still leaves
about **1.84 mm** of floor-level web on the 9 mm lattice. The nominal mouth web
remains **0.5 mm** before outward splay increases the separation.

## Validation

The generated STL is a **single connected watertight volume**.

## Files

- `hex_bit_stand_tiered_tilt_37_v11.scad` — parametric OpenSCAD source
- `hex_bit_stand_tiered_tilt_37_v11.stl` — printable mesh

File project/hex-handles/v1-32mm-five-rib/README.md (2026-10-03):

# v1 — 32 mm five-rib angular hex handle

The first accepted hex-handle design: a short, chunky handle for a nominal **26 mm hex-to-hex extension shaft**, rebuilt around the concept artwork's broad hard-edged ribs rather than the smoother eight-rib geometry used in discarded prototypes.

V1 render presentation

## Exterior geometry

- overall length: **32.0 mm**
- nominal circumscribed envelope parameter: **28 mm**
- measured exported-STL extents: approximately **26.17 × 27.52 × 32.00 mm**
- **5 ribs**, spaced **72°** apart
- rib crest width: **3.6 mm**
- broad planar recessed panels between ribs
- piecewise-linear shoulders and polygonal double collar
- no general body fillets
- only the exposed tail tip uses a **1.4 mm** comfort roundover

Fine surface texture is intentionally excluded from the CAD. It can be added after export with a mesh modifier without changing the functional socket geometry.

## Shaft socket

- nominal socket: **6.4 mm flat-to-flat**
- nominal shaft length: **26 mm**
- full-size socket depth: **26.3 mm**, including **0.3 mm seating allowance**
- two outward epoxy reservoirs centred at:
  - **8.77 mm** from the mouth
  - **17.53 mm** from the mouth
- reservoir size: **8.8 mm AF**
- reservoir flat land: **1.6 mm**
- reservoir transition chamfer: **1.4 mm** at each end
- continuous axial vent: **2.4 mm diameter**
- tail vent exit: **3.6 mm diameter** with a **0.65 mm** chamfer

The epoxy features expand outward from the 6.4 mm shaft path; they do not create inward projections that could block insertion.

## Mouth-down printing

The STL is oriented with the **hex opening at Z = 0**, directly on the build plate, and the rounded tail at Z = 32 mm.

After the 26.3 mm full-size socket, a **2.0 mm tapered roof** closes toward the vent rather than ending in an abrupt horizontal socket floor. The accepted mesh was checked at approximately **61.83° maximum non-bed downward overhang from vertical**, within the stated 65° printer capability.

Changing the exterior envelope, socket depth, roof taper, or other major geometry may invalidate that overhang result and should be rechecked in the slicer.

## Assembly

Dry-fit the metal shaft first. For permanent installation, place a controlled amount of epoxy in the bore/reservoir region, keep the vent clear, and insert the shaft slowly so air and displaced adhesive can escape through the tail.

The design has **not** been assigned a torque rating. Physical shaft fit, adhesive performance, layer adhesion, and torque strength depend on material, print settings, printer calibration, and the chosen shaft.

## Validation

The accepted STL was checked as a **single connected watertight body** after mesh processing. The 6.4 mm shaft path, five-rib count, epoxy-reservoir positions, continuous vent, overall 32 mm length, and mouth-down orientation were also checked during development.

Physical print and destructive torque testing remain to be performed.

## Files

- `hex_handle_32mm_5rib_v1.scad` — parametric OpenSCAD source
- `hex_handle_32mm_5rib_v1.stl` — printable handle mesh, generated from the source
- set `output = "socket_coupon"` in the source to generate a full-depth socket-fit coupon
- set `output = "section"` for a non-printable half-model inspection view

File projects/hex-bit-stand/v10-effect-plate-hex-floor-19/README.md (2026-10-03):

# v10 — effect-plate tiered-tilt 19-pocket stand, tapered hex floor

A refinement of `v9-effect-plate-19` based on slicer inspection.

## Pocket layout

- **19 pockets** in a radius-2 hexagonal cluster
- centre pocket: **vertical**
- 6-pocket inner ring: **4° radially outward**
- 12-pocket outer ring: **8° radially outward**
- functional pocket: **7.0 mm AF**
- pitch: **9.0 mm**
- overall envelope: approximately **53.37 × 50.79 × 14.0 mm**

The additional 1 mm of height comes from increasing the structural base from
1 mm to **2 mm** while retaining the 12 mm pocket depth.

## Centre-pocket chamfer correction

v9 applied the full 15° rotational mismatch at the bottom of every mouth
chamfer. On the vertical centre pocket that could create an inward lip at the
7 mm transition and potentially catch a bit during insertion.

v10 starts the centre lead-in on the **exact 30° shaft profile**, then twists to
the **45° / 8.5 mm AF mouth** over the 1.2 mm lead-in height. The centre still
has the deliberately misaligned visual treatment, but the entrance cannot
constrict below the 7 mm functional pocket.

The tilted inner/outer rings retain the stronger scalloped/misaligned v9 mouth
geometry that worked well in physical testing.

## Tapered hex floor relief

The v9 circular relief is replaced with the Fusion-style construction proposed
after slicer inspection:

1. Start with a **2.0 mm base**.
2. At the horizontal bottom footprint of each 7 mm pocket, taper the cavity
   downward for **1.0 mm** with a **55° inward draft**.
3. Cut the resulting smaller **hexagonal profile** straight through the
   remaining 1 mm of base.

For the centre pocket, a 55° draft over 1 mm offsets every hex face inward by
about **1.428 mm**, producing a nominal through-hole of about **4.14 mm AF**.

For tilted pockets the floor footprint is not approximated as a regular hex.
The OpenSCAD source analytically derives the **exact horizontal cross-section of
the tilted hex shaft**, offsets that polygon inward by the same 1.428 mm, and
uses the result as the through-hole. This removes the floor ledge while keeping
the requested draft angle on each face.

A 0.03 mm boolean overlap is applied equally to the upper and lower cutter
profiles to avoid coplanar zero-area remnants; it does not change the 55° taper.

## Effect-plate printing

The geometry is intended to support **top-face-down printing** on carbon,
holographic, or other effect plates. In that orientation the pocket floor
narrows progressively into the through-hole rather than terminating in a broad
horizontal bridge.

## Outer-wall styling

Carried over from v9/v7:

- no continuous waist groove
- separate inset panel on each of the **18 convex wall facets**
- **1.0 mm border**
- **1.2 mm recess depth**
- **50° taper**
- softened lower lip and **0.4 mm lower-edge chamfer** retained

## Validation

The generated STL is a **single connected watertight volume**.

## Files

- `hex_bit_stand_effect_plate_19_v10.scad` — parametric OpenSCAD source
- `hex_bit_stand_effect_plate_19_v10.stl` — printable mesh

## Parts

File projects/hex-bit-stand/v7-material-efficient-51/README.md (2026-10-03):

# v7 — material-efficient dense 51-pocket stand

A material-reduction derivative of `v4-dense-51`.

## Changes from v4

- **5.6 mm circular through-hole** through the 1 mm floor beneath every bit pocket.
- The old continuous recessed waist/indent around the outside is removed.
- Each of the **16 actual planar outer-wall faces** gets its own recessed panel.
- Each panel starts **1.0 mm from every face edge**.
- Panel recess depth: **1.2 mm**.
- Panel side taper: **50°**, narrowing into the wall.
- The softened lower lip and 0.4 mm lower-edge chamfer are retained.

## Core geometry

- Capacity: **51 bits**
- Layout: **6–7–8–9–8–7–6**
- Functional pocket: **7.0 mm AF**
- Pocket depth: **12.0 mm**
- Base thickness: **1.0 mm**
- Pocket pitch: **8.8 mm**
- Overall envelope: approximately **84.6 × 62.12 × 13.0 mm**

The 5.6 mm floor hole leaves **0.7 mm of support at the middle of each hex flat**,
so a nominal 1/4-inch bit cannot simply fall through the floor opening.

## Why the panel depth is 1.2 mm

The vertical v4 wall resolves into 16 planar faces. With a 1 mm border, the
shortest face still leaves enough room for a 50° tapered recess at 1.2 mm depth.
At the portions nearest the straight 7 mm pockets, this retains about **1.8 mm**
of wall — three 0.6 mm extrusion widths.

## Material comparison

CAD solid volume is approximately:

- current v4 baseline: **28.69 cm³**
- this v7 variant: **26.13 cm³**

That is about **8.9% less solid-model volume** despite removing the
old waist groove. Actual filament savings depend on slicer perimeter/infill
settings.

## Printing

Designed for a **0.6 mm nozzle** and intended to remain support-free.

The floor-relief holes start at the build plate, so they require no bridging.
The 50° recessed-panel transitions are intended to remain printable in the
normal base-down orientation.

## Files

- `hex_bit_stand_material_efficient_51_v7.scad` — parametric source
- `hex_bit_stand_material_efficient_51_v7.stl` — printable mesh

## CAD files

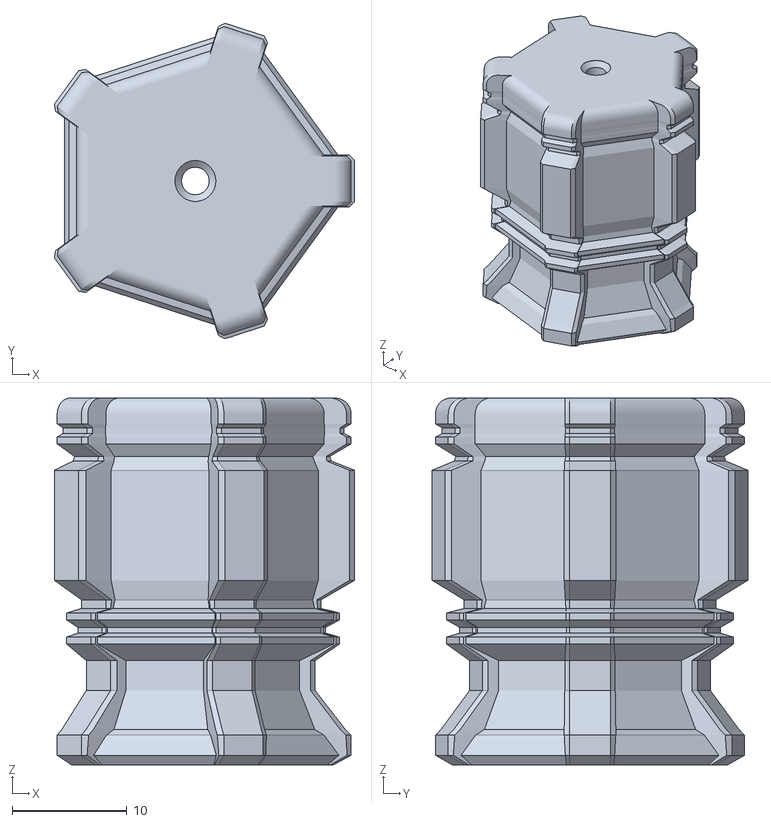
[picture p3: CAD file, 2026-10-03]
project/hex-handles/v1-32mm-five-rib/hex_handle_32mm_5rib_v1.stl
26.2 x 27.5 x 32.0

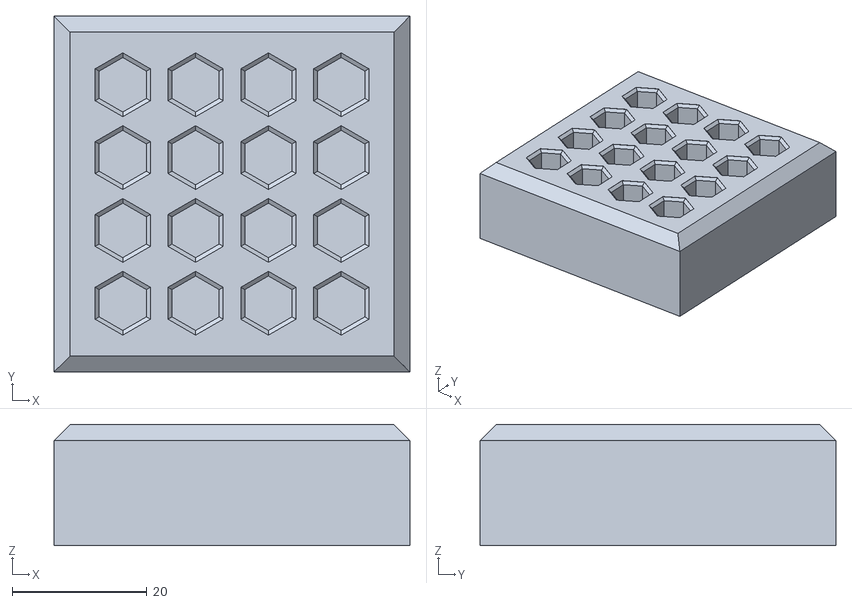
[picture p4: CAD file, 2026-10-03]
projects/hex-bit-stand/v1-grid-16/hex_bit_stand_16.stl
52.8 x 52.8 x 18.0

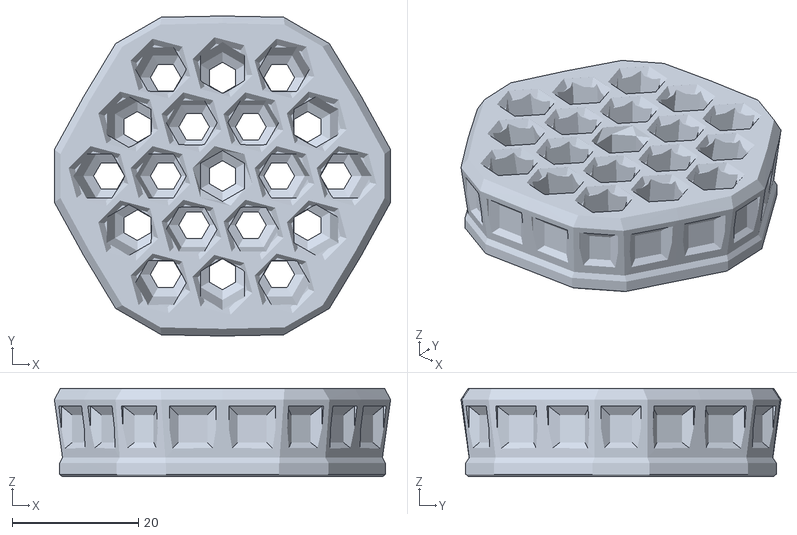
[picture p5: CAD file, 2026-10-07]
projects/hex-bit-stand/v10-effect-plate-hex-floor-19/hex_bit_stand_effect_plate_19_v10.stl
53.4 x 50.8 x 14.0

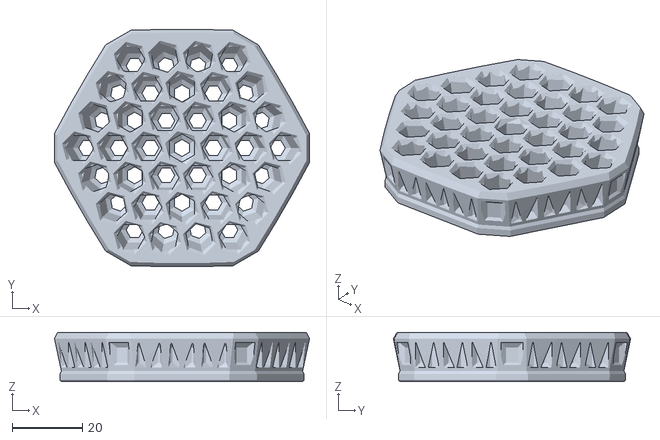
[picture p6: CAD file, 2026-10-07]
projects/hex-bit-stand/v11-tiered-tilt-37/hex_bit_stand_tiered_tilt_37_v11.stl
72.8 x 67.8 x 14.0

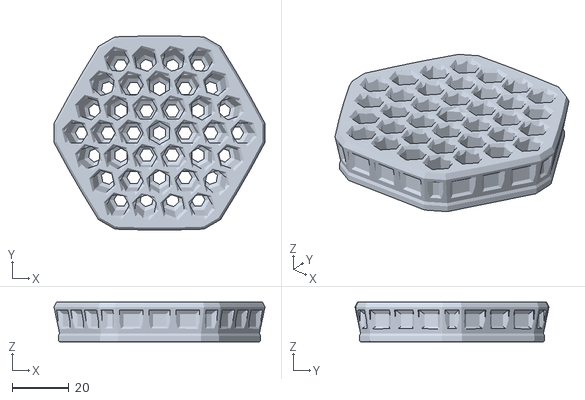
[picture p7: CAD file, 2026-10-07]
projects/hex-bit-stand/v12-clean-wall-37/hex_bit_stand_tiered_tilt_37_v12.stl
74.0 x 68.0 x 14.0

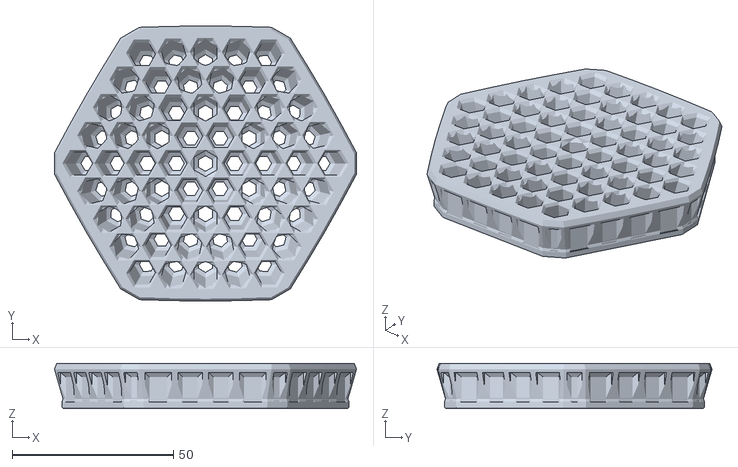
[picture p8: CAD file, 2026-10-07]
projects/hex-bit-stand/v14-tiered-tilt-61/hex_bit_stand_tiered_tilt_61_v14.stl
93.5 x 85.2 x 14.0

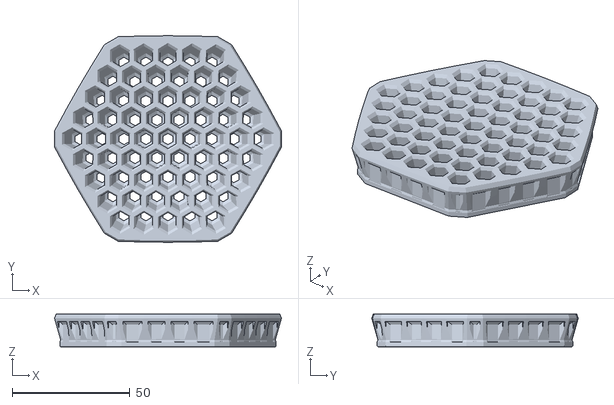
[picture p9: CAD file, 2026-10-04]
projects/hex-bit-stand/v15-continuous-web-61/hex_bit_stand_continuous_web_61_v15.stl
96.3 x 87.7 x 14.0

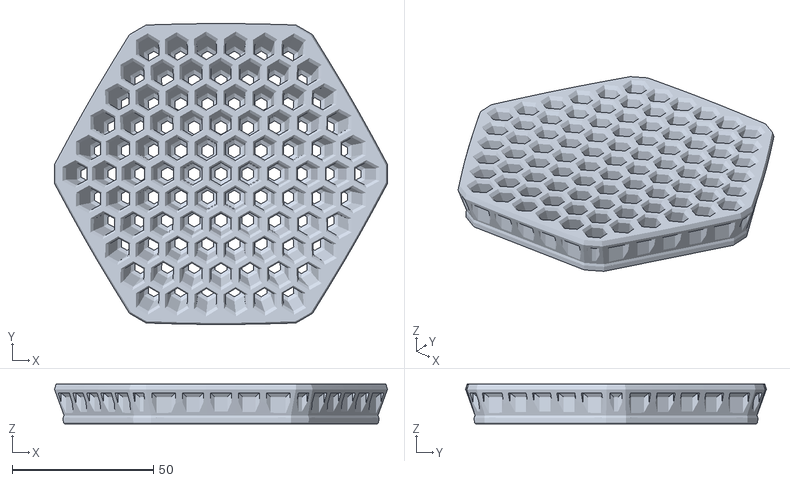
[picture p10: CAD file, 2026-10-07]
projects/hex-bit-stand/v16-continuous-web-91/hex_bit_stand_continuous_web_91_v16.stl
118.0 x 106.6 x 14.0

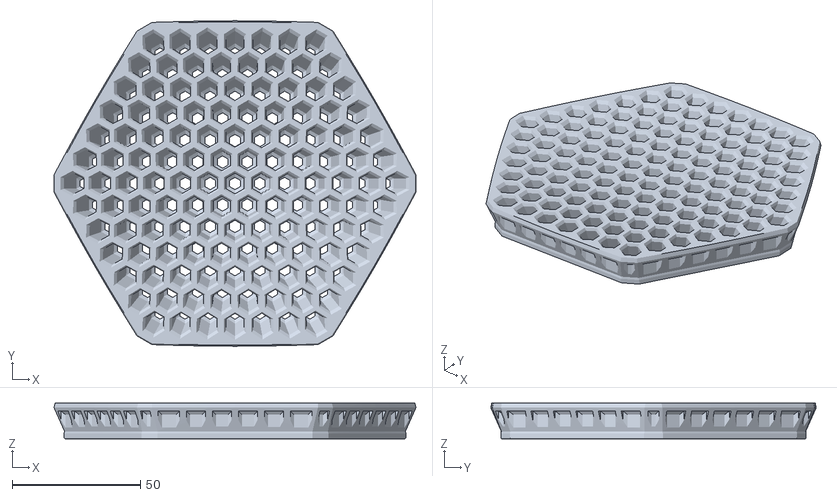
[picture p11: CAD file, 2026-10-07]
projects/hex-bit-stand/v17-continuous-web-127/hex_bit_stand_continuous_web_127_v17.stl
141.0 x 126.8 x 14.0

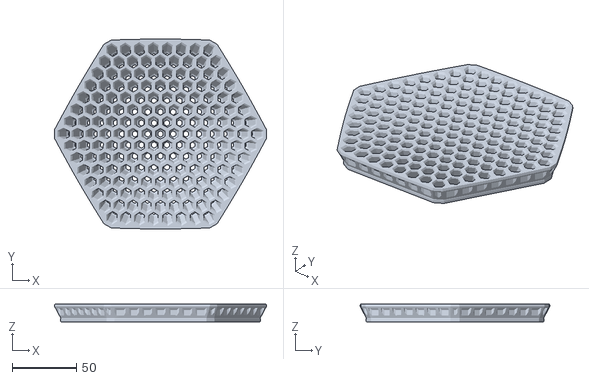
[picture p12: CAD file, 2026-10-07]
projects/hex-bit-stand/v18-continuous-web-169/hex_bit_stand_continuous_web_169_v18.stl
165.5 x 148.3 x 14.0

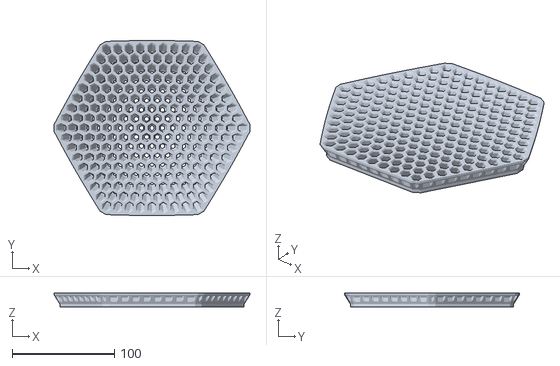
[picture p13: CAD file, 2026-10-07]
projects/hex-bit-stand/v19-continuous-web-217/hex_bit_stand_continuous_web_217_v19.stl
192.0 x 171.5 x 14.0

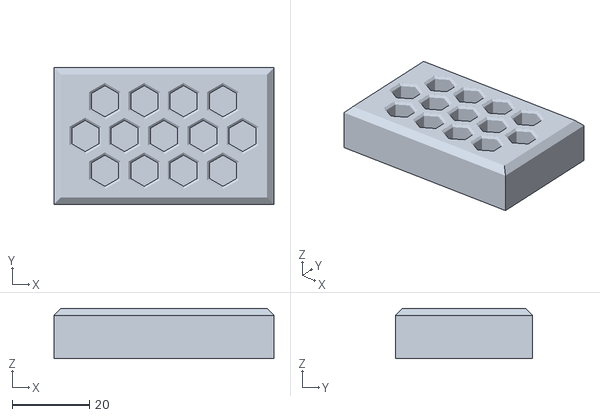
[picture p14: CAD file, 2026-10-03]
projects/hex-bit-stand/v2-hex-pattern-13/hex_bit_stand_hexpattern_v2.stl
57.0 x 35.5 x 13.0

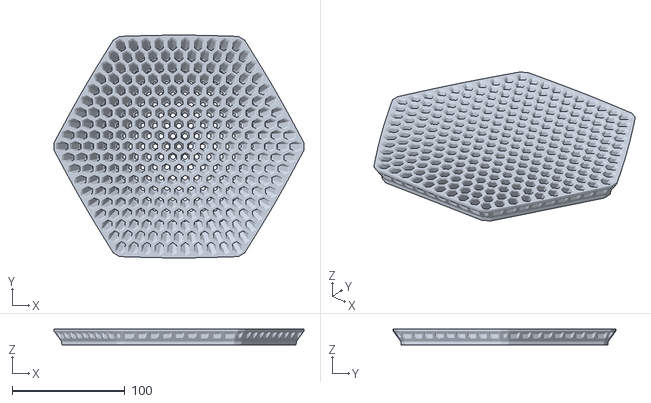
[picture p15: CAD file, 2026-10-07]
projects/hex-bit-stand/v20-continuous-web-271/hex_bit_stand_continuous_web_271_v20.stl
221.6 x 197.5 x 14.0

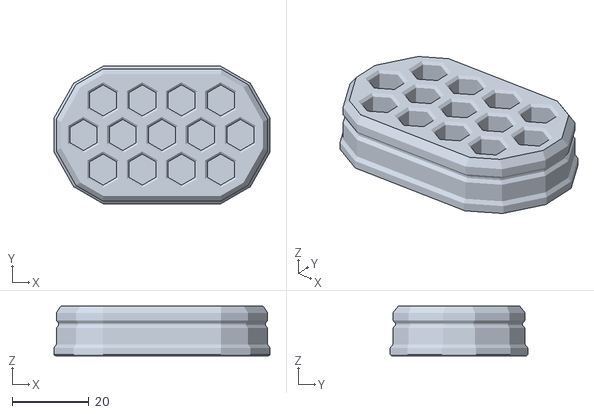
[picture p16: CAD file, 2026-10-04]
projects/hex-bit-stand/v3-contoured-13/hex_bit_stand_contoured_v3.stl
56.2 x 35.8 x 13.0

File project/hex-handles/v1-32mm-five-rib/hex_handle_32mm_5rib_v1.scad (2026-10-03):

/*
 HEX HANDLE V1 — 32 mm / FIVE HARD-EDGED RIBS
 Units: millimetres. Standalone OpenSCAD source; no external libraries.

 Published V1. Rebuilt from scratch after two discarded concept-matching prototypes.
 - Exactly five ribs, at 72 degree intervals, on the main grip and neck.
 - Flat rib crests, explicit edge chamfers, planar recessed panels.
 - Piecewise-linear shoulders and polygonal double collar: no body fillets.
 - Only the last 1.4 mm of the tail has an axial comfort roundover.
 - 6.4 mm A/F hex; 26.3 mm full-size depth; two outward epoxy reservoirs.
 - A tapered roof connects the socket to a continuous 2.4 mm tail vent.

 PRINT COORDINATES: hex mouth on Z=0 / bed. Tail at Z=32.
 Export output="handle" for the complete printable part.
 output="section" is a HALF-MODEL for inspection, NOT for printing as a handle.
 The mouth-down roof taper avoids an unsupported abrupt socket floor.

 Width is a design choice: default 28 mm circumscribed envelope, not a promise
 of a 28 x 28 bounding box (a five-fold outline has unequal axis extents).
 Geometry is not physically torque-tested or calibrated to a particular printer.
*/

/* [Output] */
output = "handle"; // [handle,section,socket_coupon]

/* [Exterior] */
handle_length = 32;         // Never above 32 mm for this design.
envelope_diameter = 28;     // Circumscribed XY envelope; default is intentionally stubby.
rib_count = 5;              // Fixed by the design brief; do not increase to eight.
body_rotation = 0;          // Rotation of five-rib pattern, degrees.
rib_crest_width = 3.6;      // Flat land width at the default 28 mm envelope.
tail_roundover = 1.4;       // Axial/radial roundover at the exposed tail ONLY.
tail_roundover_steps = 16;

/* [Socket] */
socket_af = 6.4;            // Exact nominal CAD flat-to-flat opening.
shaft_length = 26;
seating_allowance = 0.3;
socket_depth = shaft_length + seating_allowance;
socket_rotation = 30;      // Hex has flats parallel to Y at default.
entry_chamfer_depth = 0.8;
entry_chamfer_af = 7.8;
epoxy_pocket_af = 8.8;
epoxy_pocket_land = 1.6;
epoxy_pocket_chamfer = 1.4; // Each end; 4.4 mm total height per pocket.

/* [Vent and mouth-down roof] */
vent_diameter = 2.4;
roof_taper_depth = 2.0;    // Begins AFTER the 26.3 mm full-size socket.
roof_tip_af = 2.0;         // Ends wholly inside the circular vent.
vent_exit_diameter = 3.6;
vent_exit_chamfer_depth = 0.65;
vent_segments = 96;

/* [Fit coupon] */
coupon_diameter = 15;

/* [Hidden] */
eps = 0.02;
sx = envelope_diameter / 28;
sz = handle_length / 32;

assert(rib_count == 5, "This revision requires exactly five ribs.");
assert(handle_length <= 32, "Overall length must not exceed 32 mm.");
assert(handle_length > socket_depth + roof_taper_depth + vent_exit_chamfer_depth,
       "Not enough tail beyond the socket and vent transition.");
assert(envelope_diameter >= 24 && envelope_diameter <= 36,
       "Envelope parameter is intended for 24..36 mm; recheck overhangs if changed.");
assert(tail_roundover > 0 && tail_roundover <= 2.0);
assert(tail_roundover_steps >= 8);
assert(socket_af > vent_diameter && entry_chamfer_af >= socket_af);
assert(entry_chamfer_depth > 0);
assert(epoxy_pocket_af > socket_af && epoxy_pocket_chamfer > 0 && epoxy_pocket_land > 0);
assert(socket_depth/3 > 2*epoxy_pocket_chamfer + epoxy_pocket_land,
       "Epoxy pockets overlap.");
assert(socket_depth/3 - epoxy_pocket_land/2 - epoxy_pocket_chamfer > entry_chamfer_depth,
       "First epoxy pocket overlaps entry chamfer.");
assert(roof_tip_af/sqrt(3) < vent_diameter/2,
       "Roof tip must terminate INSIDE the round vent.");
assert(vent_exit_diameter >= vent_diameter && vent_exit_diameter < socket_af);
assert(coupon_diameter > 2*epoxy_pocket_af/sqrt(3) + 3);

// Thirty perimeter vertices, not a rounded polar surface. Each sector uses
// Cartesian rib coordinates. Its flank top and foot share the same local Y,
// so the tapered rib walls remain single PLANES, not twisted loft surfaces.
// There are six real corners per rib: foot, bevel, crest, crest, bevel, foot.

// [height at L=32, crest circumradius, recess radius, crest chamfer radial depth]
// The long grip is a true constant polygonal prism from Z=16.1 to Z=25.7.
// Collar ramps deliberately use slopes steeper than 45 degrees from vertical.
function hard_sections() = [
 [ 0.00,12.15,11.70,0.25], // Flat mouth-down footprint, no elephant-foot lip.
 [ 0.85,13.70,12.70,0.35], // Hard, steep head chamfer.
 [ 2.60,13.70,11.45,0.45], // Five clearly cut head flutes.
 [ 3.10,13.20,10.65,0.45],
 [ 6.50,10.60, 9.35,0.40], // Angular neck taper, not a fillet.
 [ 9.10,10.60, 9.35,0.40],
 [10.55,12.70,12.25,0.30], // First five-sided collar.
 [11.15,12.70,12.25,0.30],
 [11.50,11.50,11.15,0.25], // Recess between collars.
 [12.00,11.50,11.15,0.25],
 [12.65,12.70,12.25,0.30], // Second collar.
 [13.25,12.70,12.25,0.30],
 [13.65,11.10,10.60,0.30],
 [14.40,11.10,10.45,0.35],
 [16.10,14.00,10.95,0.45], // Five broad-ended, raised grip ribs.
 [25.70,14.00,10.95,0.45],
 [26.50,12.00,10.60,0.40], // Straight chamfered rib termination.
 [26.90,11.85,10.45,0.30],
 [28.00,13.70,11.45,0.40], // Five-lobed tail pads.
 [28.60,13.70,11.45,0.40],
 [28.90,13.10,11.45,0.35], // Shallow belt across tail pads.
 [29.40,13.10,11.45,0.35],
 [29.75,13.70,11.45,0.40]
];

function exterior_sections() = concat(
 [for(s=hard_sections()) [s[0]*sz,s[1]*sx,s[2]*sx,s[3]*sx]],
 [for(i=[0:tail_roundover_steps])
   let(a=90*i/tail_roundover_steps,
       dr=tail_roundover*(1-cos(a)))
   [handle_length-tail_roundover+tail_roundover*sin(a),
    13.7*sx-dr, 11.45*sx-dr, 0.4*sx]]
);

function rib_xy(s,k) =
 let(w=rib_crest_width*sx/2, b=s[3], wf=w+b,
     crest=sqrt(s[1]*s[1]-w*w), foot=sqrt(s[2]*s[2]-wf*wf))
 k==0 ? [foot,-wf] :
 k==1 ? [crest-b,-wf] :
 k==2 ? [crest,-w] :
 k==3 ? [crest,w] :
 k==4 ? [crest-b,wf] : [foot,wf];

module exterior() {
 sections=exterior_sections();
 n=rib_count*6;
 assert(sections[len(hard_sections())][0] > sections[len(hard_sections())-1][0],
        "Tail roundover overlaps preceding pad detail.");
 points=[for(s=sections, j=[0:rib_count-1], k=[0:5])
   let(a=body_rotation+360*j/rib_count,p=rib_xy(s,k))
   [p[0]*cos(a)-p[1]*sin(a),p[0]*sin(a)+p[1]*cos(a),s[0]]];
 faces=concat(
   [[for(i=[n-1:-1:0]) i]],
   [for(j=[0:len(sections)-2],i=[0:n-1])
     [j*n+i,j*n+(i+1)%n,(j+1)*n+(i+1)%n]],
   [for(j=[0:len(sections)-2],i=[0:n-1])
     [j*n+i,(j+1)*n+(i+1)%n,(j+1)*n+i]],
   [[for(i=[0:n-1]) (len(sections)-1)*n+i]]
 );
 polyhedron(points=points,faces=faces,convexity=20);
}

// One hexagonal loft: reliefs expand OUTWARD, never into the bit's path.
// The final taper builds a printable mouth-down roof, with no horizontal
// socket-floor bridge. The 2.4 mm vent cuts right through the tapered tip.
module hex_socket_and_roof() {
 h=epoxy_pocket_land/2;
 t=h+epoxy_pocket_chamfer;
 c1=socket_depth/3;
 c2=2*socket_depth/3;
 rows=[
  [-eps,entry_chamfer_af],
  [0,entry_chamfer_af],
  [entry_chamfer_depth,socket_af],
  [c1-t,socket_af],
  [c1-h,epoxy_pocket_af],
  [c1+h,epoxy_pocket_af],
  [c1+t,socket_af],
  [c2-t,socket_af],
  [c2-h,epoxy_pocket_af],
  [c2+h,epoxy_pocket_af],
  [c2+t,socket_af],
  [socket_depth,socket_af],
  [socket_depth+roof_taper_depth,roof_tip_af]
 ];
 points=[for(s=rows,i=[0:5])
   let(a=socket_rotation+60*i,r=s[1]/sqrt(3))
   [r*cos(a),r*sin(a),s[0]]];
 faces=concat(
   [[5,4,3,2,1,0]],
   [for(j=[0:len(rows)-2],i=[0:5])
     [6*j+i,6*j+(i+1)%6,6*(j+1)+(i+1)%6]],
   [for(j=[0:len(rows)-2],i=[0:5])
     [6*j+i,6*(j+1)+(i+1)%6,6*(j+1)+i]],
   [[for(i=[0:5]) 6*(len(rows)-1)+i]]
 );
 polyhedron(points=points,faces=faces,convexity=12);
}

module cavities() {
 hex_socket_and_roof();
 translate([0,0,socket_depth-eps])
   cylinder(d=vent_diameter,h=handle_length-socket_depth+2*eps,$fn=vent_segments);
 translate([0,0,handle_length-vent_exit_chamfer_depth])
   cylinder(d1=vent_diameter,d2=vent_exit_diameter,
            h=vent_exit_chamfer_depth,$fn=vent_segments);
 translate([0,0,handle_length-eps])
   cylinder(d=vent_exit_diameter,h=2*eps,$fn=vent_segments);
}

module handle() {
 difference() { exterior(); cavities(); }
}

module section() {
 // Keep the +Y half; socket, both reservoirs, roof and vent are exposed.
 intersection() {
  handle();
  translate([-envelope_diameter,0,-1])
   cube([2*envelope_diameter,envelope_diameter,handle_length+2]);
 }
}

module socket_coupon() {
 // Smaller body, full-depth cavity. Print with its hex opening on the bed too.
 difference() {
  union() {
   cylinder(d=coupon_diameter,h=handle_length-0.7,$fn=80);
   translate([0,0,handle_length-0.7])
    cylinder(d1=coupon_diameter,d2=coupon_diameter-1.4,h=0.7,$fn=80);
  }
  cavities();
 }
}

if(output=="handle") handle();
else if(output=="section") section();
else if(output=="socket_coupon") socket_coupon();
else assert(false,"Unknown output; use handle, section or socket_coupon.");

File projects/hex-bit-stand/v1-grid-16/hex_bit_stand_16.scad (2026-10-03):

// 16-bit hex driver stand
// Designed for 0.6 mm nozzle printing with no supports.
// Units: millimetres

$fn = 48;

// ---------- User parameters ----------
columns = 4;
rows = 4;

hex_flat_to_flat = 7.0;       // straight pocket section
pocket_depth = 12.0;
pocket_mouth_chamfer_h = 0.6;
pocket_mouth_flat_to_flat = 8.2;

pitch_x = 10.8;               // 18 nozzle widths @ 0.6 mm
pitch_y = 10.8;

body_x = 52.8;                // 88 nozzle widths
body_y = 52.8;
body_h = 18.0;
outer_top_chamfer = 2.4;      // 4 nozzle widths; 45 degree

// ---------- Derived values ----------
hex_r = hex_flat_to_flat / sqrt(3);              // circumradius
mouth_hex_r = pocket_mouth_flat_to_flat / sqrt(3);

module hex_prism(r, h) {
    // Rotate 30 degrees so the named dimension is flat-to-flat on X/Y.
    linear_extrude(height = h)
        rotate(30)
            circle(r = r, $fn = 6);
}

module top_chamfered_block(x, y, h, c) {
    assert(c > 0 && c < h, "outer_top_chamfer must be > 0 and < body_h");
    assert(2*c < min(x, y), "outer_top_chamfer too large for body footprint");

    union() {
        // Straight lower body.
        translate([-x/2, -y/2, 0])
            cube([x, y, h-c]);

        // 45-degree top-edge chamfer.
        hull() {
            translate([-x/2, -y/2, h-c-0.02])
                cube([x, y, 0.02]);
            translate([-(x-2*c)/2, -(y-2*c)/2, h-0.02])
                cube([x-2*c, y-2*c, 0.02]);
        }
    }
}

module bit_pocket() {
    // Main 7.0 mm AF pocket. Extend slightly upward to avoid coplanar artifacts.
    translate([0, 0, body_h - pocket_depth - 0.02])
        hex_prism(hex_r, pocket_depth - pocket_mouth_chamfer_h + 0.04);

    // 0.6 mm tall lead-in taper. The functional pocket below remains 7.0 mm AF.
    hull() {
        translate([0, 0, body_h - pocket_mouth_chamfer_h - 0.02])
            hex_prism(hex_r, 0.02);
        translate([0, 0, body_h - 0.02])
            hex_prism(mouth_hex_r, 0.04);
    }
}

module stand() {
    difference() {
        top_chamfered_block(body_x, body_y, body_h, outer_top_chamfer);

        for (ix = [0 : columns-1])
            for (iy = [0 : rows-1]) {
                x = (ix - (columns-1)/2) * pitch_x;
                y = (iy - (rows-1)/2) * pitch_y;
                translate([x, y, 0])
                    bit_pocket();
            }
    }
}

// Basic sanity checks.
assert(columns * rows >= 12, "Stand must hold at least 12 bits");
assert(body_h > pocket_depth, "Pocket depth must leave a closed floor");
assert(pocket_mouth_flat_to_flat >= hex_flat_to_flat,
       "Pocket mouth must not be smaller than the straight pocket");

stand();

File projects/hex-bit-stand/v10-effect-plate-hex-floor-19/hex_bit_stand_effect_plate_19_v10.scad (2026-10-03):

// Effect-plate tiered-tilt hex-bit stand, v10
// Derived from v9-effect-plate-19.
//
// 19 pockets: centre vertical, 6 inner-ring at 4 degrees, 12 outer-ring at 8 degrees.
//
// v10 retains v9 styling/tilt, and revises floor/mouth geometry:
// - keep v7-style individual outer-wall inset panels; no continuous waist groove
// - retain deliberately misaligned/scalloped chamfers on tilted pockets
// - centre pocket lead-in starts aligned to the shaft, eliminating its insertion-blocking lip
// - increase structural base thickness to 2.0 mm
// - replace round floor reliefs with tapered HEX floor transitions:
//   full pocket footprint at z=2 mm -> 55-degree inward taper to z=1 mm ->
//   smaller hexagonal through-hole to the underside
// - intended for normal or top-face-down effect-plate printing
//
// Designed for a 0.6 mm nozzle; nominal top web remains 0.5 mm.
// Units: millimetres.

$fn = 48;

// ---------- Pocket geometry ----------
hex_flat_to_flat = 7.0;
pocket_depth = 12.0;
base_thickness = 2.0;
pocket_mouth_chamfer_h = 1.2;
pocket_mouth_flat_to_flat = 8.5;

// Deliberate global mouth rotation. Shaft hex is 30 degrees; mouth hex is 45 degrees.
// This produces a 15-degree equivalent mismatch for centre, corner, and edge-ring pockets.
shaft_hex_rotation = 30.0;
mouth_hex_rotation = 45.0;

pitch = 9.0;
inner_tilt_degrees = 4.0;
outer_tilt_degrees = 8.0;
centre_epsilon = 0.001;

// ---------- Upside-down / effect-plate floor relief ----------
// Fusion-style construction: make the base 2 mm thick, then taper the bottom
// of each pocket downward by 1 mm with a 55-degree inward draft. The resulting
// smaller hex face is cut straight through the remaining 1 mm of base.
floor_taper_h = 1.0;
floor_taper_degrees = 55.0;
floor_taper_inset = floor_taper_h * tan(floor_taper_degrees);
floor_hole_flat_to_flat = hex_flat_to_flat - 2*floor_taper_inset;
floor_hole_r = floor_hole_flat_to_flat / sqrt(3);
floor_boolean_overlap = 0.03; // avoid coplanar/zero-area boolean remnants

// ---------- Contoured body ----------
wall_margin = 3.0;
body_h = pocket_depth + base_thickness; // 14.0 mm total
foot_flare = 0.6;
lower_edge_chamfer = 0.4;
top_chamfer_inset = 1.2;

z0 = 0.00;
z_lower_chamfer_top = lower_edge_chamfer;
z_foot_top = 2.10;
z_foot_blend = 3.00;
z_chamfer_start = 12.20;
z_top = body_h;

// ---------- v7-style face panels ----------
panel_border = 1;
panel_depth = 1.2;
panel_taper_degrees = 50;
panel_taper_run = panel_depth * tan(panel_taper_degrees);
panel_front_outset = 1.5; // deliberately crosses the slightly sloped v8 wall

// ---------- Derived ----------
hex_r = hex_flat_to_flat / sqrt(3);
mouth_hex_r = pocket_mouth_flat_to_flat / sqrt(3);
minimum_top_web_unshifted = pitch - pocket_mouth_flat_to_flat;
minimum_straight_web_unshifted = pitch - hex_flat_to_flat;
outer_floor_projected_af = hex_flat_to_flat / cos(outer_tilt_degrees);
minimum_floor_horizontal_web = pitch - outer_floor_projected_af;
floor_support_at_flats = floor_taper_inset;

function ring_index(q, r) = max(abs(q), abs(r), abs(q + r));
function tilt_for_ring(ring) = ring == 0 ? 0 : ring == 1 ? inner_tilt_degrees : outer_tilt_degrees;
function radial_shift_at_z(z, ring) =
    ring == 0 ? 0 :
    max(0, min(body_h - base_thickness, z - base_thickness)) * tan(tilt_for_ring(ring));

function centre_x(q, r) = pitch * (q + r/2);
function centre_y(q, r) = pitch * sqrt(3)/2 * r;

module shaft_hex_2d(r) {
    rotate(shaft_hex_rotation) circle(r=r, $fn=6);
}

module mouth_hex_2d(r) {
    rotate(mouth_hex_rotation) circle(r=r, $fn=6);
}

// Body outline intentionally retains the v8 30-degree hex orientation.
// The 3 mm body margin / 1.8 mm top rim fully contains the 45-degree mouth hexes,
// while preserving the proven v8 outer silhouette and useful wall-facet sizes.
module body_hex_2d(r) {
    rotate(shaft_hex_rotation) circle(r=r, $fn=6);
}

module pocket_cluster_2d(z) {
    union() {
        for (q=[-2:2])
            for (r=[-2:2]) {
                ring=ring_index(q,r);
                if (ring <= 2) {
                    x0=centre_x(q,r);
                    y0=centre_y(q,r);
                    radius=sqrt(x0*x0+y0*y0);
                    shift=radial_shift_at_z(z,ring);
                    x=radius < centre_epsilon ? x0 : x0 + shift*x0/radius;
                    y=radius < centre_epsilon ? y0 : y0 + shift*y0/radius;
                    translate([x,y]) body_hex_2d(mouth_hex_r);
                }
            }
    }
}

module body_profile_2d(z, extra=0) {
    offset(delta=wall_margin+extra) pocket_cluster_2d(z);
}

module profile_slice(z, extra, thickness=0.03) {
    translate([0,0,z]) linear_extrude(height=thickness) body_profile_2d(z,extra);
}

module loft_segment(z1, extra1, z2, extra2) {
    hull() {
        profile_slice(z1,extra1);
        profile_slice(z2-0.03,extra2);
    }
}

module styled_body() {
    union() {
        loft_segment(z0, foot_flare-lower_edge_chamfer,
                     z_lower_chamfer_top, foot_flare);
        loft_segment(z_lower_chamfer_top, foot_flare,
                     z_foot_top, foot_flare);
        loft_segment(z_foot_top, foot_flare, z_foot_blend, 0);

        // Plain main wall: v8's continuous waist cut is intentionally removed.
        loft_segment(z_foot_blend, 0, z_chamfer_start, 0);

        loft_segment(z_chamfer_start, 0, z_top, -top_chamfer_inset);
    }
}

module shaft_hex_prism(r,h) { linear_extrude(height=h) shaft_hex_2d(r); }
module mouth_hex_prism(r,h) { linear_extrude(height=h) mouth_hex_2d(r); }

module centre_pocket() {
    translate([0,0,base_thickness])
        shaft_hex_prism(hex_r, pocket_depth-pocket_mouth_chamfer_h+0.08);

    // Centre-pocket correction: start the chamfer on the exact shaft profile so
    // there is no 7 mm rotated lip constricting bit insertion. The upper mouth
    // remains at the deliberate 45-degree orientation, so the chamfer still
    // twists/misaligns visually as it expands.
    hull() {
        translate([0,0,body_h-pocket_mouth_chamfer_h])
            shaft_hex_prism(hex_r,0.03);
        translate([0,0,body_h-0.01])
            mouth_hex_prism(mouth_hex_r,0.04);
    }
}

module outward_axis_frame(x0,y0,tilt_degrees) {
    radius=sqrt(x0*x0+y0*y0);
    ux=x0/radius; uy=y0/radius;
    s=sin(tilt_degrees); c=cos(tilt_degrees);

    xx=-uy; xy=ux; xz=0;
    yx=-c*ux; yy=-c*uy; yz=s;
    zx=s*ux; zy=s*uy; zz=c;

    multmatrix([
        [xx,yx,zx,x0],
        [xy,yy,zy,y0],
        [xz,yz,zz,base_thickness],
        [0,0,0,1]
    ]) children();
}

module tilted_shaft(x0,y0,tilt_degrees) {
    axis_length=(body_h-base_thickness)/cos(tilt_degrees);
    intersection() {
        outward_axis_frame(x0,y0,tilt_degrees)
            translate([0,0,-2]) shaft_hex_prism(hex_r,axis_length+6);
        translate([-100,-100,base_thickness])
            cube([200,200,body_h-base_thickness+10]);
    }
}

module tilted_mouth_leadin(x0,y0,ring) {
    radius=sqrt(x0*x0+y0*y0);
    ux=x0/radius; uy=y0/radius;
    z_low=body_h-pocket_mouth_chamfer_h;
    shift_low=radial_shift_at_z(z_low,ring);
    shift_top=radial_shift_at_z(body_h,ring);
    x_low=x0+shift_low*ux; y_low=y0+shift_low*uy;
    x_top=x0+shift_top*ux; y_top=y0+shift_top*uy;

    hull() {
        translate([x_low,y_low,z_low]) mouth_hex_prism(hex_r,0.03);
        translate([x_top,y_top,body_h-0.01]) mouth_hex_prism(mouth_hex_r,0.04);
    }
}

module tilted_pocket(x0,y0,ring) {
    union() {
        tilted_shaft(x0,y0,tilt_for_ring(ring));
        tilted_mouth_leadin(x0,y0,ring);
    }
}

// Exact Fusion-style tapered floor transition for normal or inverted printing.
//
// For tilted pockets the horizontal floor cross-section is an affine/sheared
// hex, not a regular 7 mm hex. We derive that exact cross-section from the shaft
// frame, then use OpenSCAD offset(delta=-inset) to create the lower profile.
// Over a 1 mm vertical drop, a 1.428 mm inward edge offset corresponds to the
// requested 55-degree inward draft on every edge. The offset profile is then
// cut straight through the remaining 1 mm of base as a hexagonal through-hole.
module floor_footprint_2d(x0,y0,ring) {
    if (ring == 0) {
        translate([x0,y0]) shaft_hex_2d(hex_r);
    } else {
        radius=sqrt(x0*x0+y0*y0);
        ux=x0/radius;
        uy=y0/radius;
        c=cos(tilt_for_ring(ring));

        // Exact horizontal slice of the tilted infinite hex prism at its
        // z=base_thickness origin. Tangential dimension is unchanged; radial
        // dimension is stretched by 1/cos(tilt).
        multmatrix([
            [-uy, -ux/c, 0, x0],
            [ ux, -uy/c, 0, y0],
            [  0,     0, 1,  0],
            [  0,     0, 0,  1]
        ]) shaft_hex_2d(hex_r);
    }
}

module floor_upper_cut_profile_2d(x0,y0,ring) {
    offset(delta=floor_boolean_overlap)
        floor_footprint_2d(x0,y0,ring);
}
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

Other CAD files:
projects/hex-bit-stand/v13-lip-edge-panels-37/hex_bit_stand_tiered_tilt_37_v13.stl
projects/hex-bit-stand/v4-dense-51/hex_bit_stand_dense_51_v4.stl
projects/hex-bit-stand/v5-dense-contoured-13/hex_bit_stand_dense_contoured_13_v6.stl
projects/hex-bit-stand/v6-outward-tilted-13/hex_bit_stand_outward_tilted_13_v6.stl
projects/hex-bit-stand/v11-tiered-tilt-37/hex_bit_stand_tiered_tilt_37_v11.scad
projects/hex-bit-stand/v12-clean-wall-37/hex_bit_stand_tiered_tilt_37_v12.scad
projects/hex-bit-stand/v13-lip-edge-panels-37/hex_bit_stand_tiered_tilt_37_v13.scad
projects/hex-bit-stand/v14-tiered-tilt-61/hex_bit_stand_tiered_tilt_61_v14.scad
projects/hex-bit-stand/v15-continuous-web-61/hex_bit_stand_continuous_web_61_v15.scad
projects/hex-bit-stand/v16-continuous-web-91/hex_bit_stand_continuous_web_91_v16.scad
projects/hex-bit-stand/v17-continuous-web-127/hex_bit_stand_continuous_web_127_v17.scad
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

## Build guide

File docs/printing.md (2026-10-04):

# Printing notes and current design rules

The primary hex-bit-stand target is a **0.6 mm nozzle**. Version-specific orientation and validation instructions take precedence over the early generic base-down notes.

## Minimum top/bottom feature width — 1.3 mm

From v15 onward, use **1.3 mm as the minimum actual solid ligament/feature width on top and bottom faces**, especially the visible face printed directly against an effect plate. This is an in-plane width requirement, not a redefinition of layer height or a statement that every Z-thickness must equal 1.3 mm.

Include material between complete pocket mouths, multi-pocket junctions, exit holes and the exterior perimeter. Account for tilt projection, hex orientation, all cutter unions and intersections, and chamfer geometry. Do not substitute nominal `pitch - flat_to_flat` for actual polygon-to-polygon measurement.

A nozzle's ability to extrude a 0.5 mm line does not make a 0.5 mm face junction a reliable design target. In the owner's v14 representative-section test, interrupted first-layer paths and seams coincided with thin junctions, producing visible gaps and blips. Measuring the supplied v14 STL found top-face gaps down to about **0.024 mm**.

The v15 correction uses aligned shaft/mouth profiles, lattice-aligned shaft roll and 9.3 mm pitch. Its exported top face has **1.424 mm minimum inter-pocket web**; the underside has **4.937 mm** between exits. It also checks the exterior rim and 83 intermediate sections. See [v15](../projects/hex-bit-stand/v15-continuous-web-61/).

A geometry pass is not a guarantee of seam-free toolpaths or a successful physical print. Inspect the first layers in the actual slicer and use a representative section/coupon before committing to the full part. Any new exception below 1.3 mm needs explicit owner agreement.

## Orientation and fit

Early vertical stands were developed base-down. The later effect-plate variants are intended to be printed **top-face-down**, so the broad pocket-opening face contacts the plate. v15 provides `print_face_down=true` and an optional nine-pocket test coupon in its source.

The functional hex pocket is **7.0 mm AF measured perpendicular to the bit axis**. A horizontal slice of a tilted pocket is slightly stretched; do not mistake that projection for changed bit clearance. Revalidate surface ligaments after changing pocket size, pitch, orientation or entrance dimensions.

The historical 0.24–0.30 mm layer-height and 3–4 perimeter suggestions were starting points, not confirmed settings for every version. The owner's slicer profile and representative print remain the manufacturing authority.

## Historical thin-web experiments

v4/v7 used nominal 0.6 mm mouth webs; several later variants used nominal 0.5 mm spacing estimates. These remain in Git as design history and are **not** certified against the current 1.3 mm minimum. The newer rule supersedes those assumptions for future designs and revisions; it does not silently modify the earlier STLs.

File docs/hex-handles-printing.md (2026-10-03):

# Hex handles — printing and installation notes

These notes apply to the compact handles under `project/hex-handles/`. They are separate from the hex-bit-stand printing notes because the handles have different strength, fit, and assembly constraints.

## Orientation

Print V1 with the **hex socket opening directly on the build plate** and the tail pointing upward.

This orientation:

- keeps the shaft axis aligned with the layer stack
- gives the socket mouth direct dimensional support from the bed
- lets the internal tapered roof close toward the small vent without a broad horizontal bridge
- places the rounded tail at the top of the print

The accepted V1 geometry was developed around a printer capable of approximately **65° overhangs from vertical**; its checked non-bed downward-facing maximum was approximately **61.83°**.

## Socket fit

The CAD socket is **6.4 mm flat-to-flat** for a nominal 1/4-inch / 6.35 mm hex shaft.

That **0.025 mm nominal per-side clearance (0.05 mm across flats) is small**. Real fit depends strongly on:

- XY calibration
- first-layer/elephant-foot compensation
- filament shrinkage
- slicer line-width behaviour
- the actual extension shaft dimensions

Before committing a full handle or using epoxy, generate the source's `socket_coupon` output and test the actual shaft. Adjust `socket_af` if required.

## Slicer checks

Before printing a modified version:

1. inspect the first few layers around the hex mouth for elephant-foot intrusion;
2. inspect both epoxy reservoirs to make sure no support material or slicer artefact blocks the shaft path;
3. confirm the socket-to-vent roof is being printed as successive supported perimeters rather than a broad bridge;
4. verify the tail vent remains open to the outside;
5. recheck overhangs after changing the exterior envelope or axial section positions.

Internal supports are not intended.

## Strength

No torque rating is claimed. For a working tool handle, use a material and print strategy appropriate to the expected load. Increasing perimeter count is generally more useful to this shell-like part than relying only on high sparse infill.

The **26 mm metal shaft is intentionally embedded through most of the 32 mm handle** to reduce the length of unsupported printed material that could otherwise shear along a layer interface.

## Epoxy installation

For permanent installation:

1. dry-fit the shaft and verify full seating;
2. remove it and confirm the **2.4 mm tail vent** is clear;
3. apply a controlled amount of suitable epoxy inside the socket/reservoir region;
4. insert the shaft slowly while keeping the handle oriented so displaced air and excess adhesive can escape through the vent;
5. wipe away expelled adhesive before it cures;
6. leave the assembly undisturbed for the adhesive manufacturer's full cure time.

The two enlarged internal waist regions are intended to form mechanical epoxy keys around the shaft without narrowing the 6.4 mm insertion path.

## Surface finishing

The repository CAD intentionally omits the fine surface texture visible on earlier physical handles. Apply decorative/traction texture only after the functional CAD is complete, and avoid modifying the socket, vent, mouth, or shaft-seating surfaces.

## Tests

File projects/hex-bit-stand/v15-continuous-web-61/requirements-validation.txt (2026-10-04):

numpy==2.3.5
shapely==2.1.2
trimesh==4.11.1
networkx>=3.4,<4
scipy>=1.14,<2

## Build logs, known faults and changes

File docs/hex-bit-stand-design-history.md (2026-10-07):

# Hex bit stand design history

The hex bit stand has evolved through twenty committed design iterations.

## v1 — 16-pocket grid

The initial design established the basic fit and print constraints: 7.0 mm AF pockets, 12 mm depth, a 0.6 mm lead-in, and a substantial top chamfer. It used a simple 4 × 4 rectangular grid and a 6 mm floor.

## v2 — hex-pattern layout

The layout changed to a 4–5–4 staggered cluster and the floor was reduced to 1 mm. This removed a large amount of unnecessary material while retaining easy-access 7.0 mm AF pockets.

## v3 — contoured body

The rectangular outer block was replaced with a body derived from the outer pocket envelope. A flared foot, recessed waist band, and contoured top chamfer added visual character without requiring supports.

## v4 — dense 51-pocket stand

Capacity increased from 13 to 51 pockets using a 6–7–8–9–8–7–6 lattice. Centre pitch was reduced to 8.8 mm, leaving 1.8 mm between the functional 7.0 mm pocket sections and 0.6 mm at the very top of adjacent 8.2 mm lead-ins.

## v5 — dense contoured 13-pocket stand

The compact 4–5–4 format was combined with v4's 8.8 mm dense lattice. The lower lip was then revised after physical handling feedback: its full-height section was increased by 1.2 mm and a 0.4 mm × 0.4 mm 45° chamfer was added around the bottom perimeter.

The same lower-lip comfort revision was backported to the contoured v3 and v4 sources.

## v6 — outward-tilted dense 13-pocket stand

The compact dense layout was adapted so the centre pocket remains vertical while the twelve surrounding pockets tilt **10° radially outward**. To prevent the dense pocket shafts from converging and intersecting below the surface, the v5 floor-centre lattice is retained and each tilted axis splays outward as it rises. The outer mouth centres therefore move about **2.12 mm outward** at the top. The body contour follows that splay through height, and the softened lower-lip treatment is retained.

Physical testing confirmed that the outward-splayed arrangement works well with long driver bits. The horizontally generated mouth chamfers intersect the rotated tilted shafts with a visible rotational mismatch; that accidental scalloped detail was retained as a deliberate feature in later tilted variants.

## v7 — material-efficient dense 51-pocket stand

The v4 high-capacity geometry was revisited for lower material use. Each pocket now has a **5.6 mm circular through-hole** through its 1 mm floor, leaving 0.7 mm support at the middle of each 7 mm hex flat. The old continuous outer waist recess was removed and replaced by separate recessed panels on all **16 planar wall faces**. Each panel keeps a **1 mm border**, cuts **1.2 mm** into the wall, and uses a **50° taper**. The result remains a single watertight solid and reduces CAD solid volume by about **8.9%** relative to the current v4 baseline.

## v8 — tiered-tilt 19-pocket stand

The successful v6 concept was expanded into a true radius-2 hexagonal lattice: **1 centre + 6 inner-ring + 12 outer-ring pockets**. The centre remains vertical, the inner ring tilts **4° outward**, and the outer ring tilts **8° outward**. This produces a much squarer footprint of roughly **53.37 × 50.79 mm** (about **1.05:1**) while keeping a compact 19-bit capacity.

Pocket pitch is **9.0 mm**. The mouth chamfer was enlarged to **1.2 mm high / 8.5 mm AF**, leaving a nominal **0.5 mm top web** before the splay increases separation. The mouth chamfers deliberately remain globally oriented while the tilted shaft hexes rotate into radial local frames, preserving and strengthening the rotationally misaligned/scalloped appearance seen on the printed v6.

A physical v8 print confirmed the two-angle arrangement: with bits inserted, the 4°/8° splay is visually clear and provides useful separation, while the empty stand does not look conspicuously tilted.

## v9 — effect-plate tiered-tilt 19-pocket stand

v9 keeps the proven v8 **0° / 4° / 8°** tilt scheme and near-square footprint while refining both the wall treatment and print orientation.

The continuous waist groove is removed and replaced by v7-style recessed panels on the **18 actual convex outer-wall facets**. Each panel keeps a **1 mm edge border**, uses the same **1.2 mm recess depth** as v7, and tapers inward at **50°**.

The mouth geometry enforces a deliberate **15° rotational mismatch** by using 30° shaft hexes and 45° horizontal mouth hexes. Slicer inspection showed that this can create an undesirable inward lip on the vertical centre pocket because its lower 7 mm chamfer profile is itself rotated relative to the shaft.

v9 also experimented with circular pocket-floor reliefs for effect-plate printing. Slicer inspection showed that the intended pocket-base transition was not expressed cleanly enough.

## v10 — tapered-hex-floor effect-plate 19-pocket stand

v10 keeps the successful v8/v9 **0° / 4° / 8°** pocket splay and the v7-style inset wall panels, but revises the two problem areas found in the v9 slicer preview.

The centre lead-in now begins on the **exact 30° / 7 mm shaft profile** and twists only as it expands toward the **45° / 8.5 mm mouth**. This preserves the misaligned visual treatment while eliminating the potentially insertion-blocking 7 mm lip. The tilted rings retain the stronger scalloped v9 treatment that had already worked in physical testing.

The structural base increases from **1 mm to 2 mm** while retaining the full **12 mm pocket depth**, giving a 14 mm total stand height. At the bottom of every pocket, its exact horizontal hex cross-section is extruded downward for **1 mm with a 55° inward draft**. The resulting smaller hex profile then cuts straight through the remaining 1 mm of base.

For the vertical centre pocket, the 55° taper offsets each face inward by about **1.428 mm**, producing a nominal through-hole of about **4.14 mm AF**. For tilted pockets, the source analytically derives the exact affine/sheared horizontal cross-section of the tilted shaft and offsets that polygon inward by the same amount, so the taper meets the pocket floor without a ledge.

This creates a much cleaner self-supporting cavity for **top-face-down effect-plate printing** while retaining a true hexagonal through-hole instead of the v9 circular relief.

## v11 — tiered-tilt 37-pocket stand

v11 expands the proven v10 radius-2 design into a **radius-3 hexagonal lattice** with **37 pockets**: 1 centre, 6 in ring 1, 12 in ring 2, and 18 in the new outer ring.

The tilt bands are now **0° / 4° / 8° / 12°**. The new 18-pocket outer ring tilts **12° radially outward**, shifting its mouth centres about **2.55 mm outward** over the 12 mm pocket height. Even at 12°, the 7 mm shaft's horizontal projection leaves roughly **1.84 mm** of floor-level web on the 9 mm lattice.

The v10 2 mm base, exact 55° tapered hex floor reliefs, corrected centre lead-in, effect-plate orientation, misaligned/scalloped mouth treatment, lower-lip chamfer, and per-face wall panels are retained.

The larger radius-3 outline produces **42 actual outer-wall facets**, including several shorter facets. The wall-panel system therefore keeps the v10 **1.2 mm nominal recess depth** but adaptively reduces depth only on the shortest facets to preserve at least a **0.5 mm back-flat**.

The overall envelope is approximately **72.84 × 67.77 × 14.0 mm**, maintaining a near-square **1.08:1** footprint despite nearly doubling the v10 pocket count.

## v12 — clean-wall tiered-tilt 37-pocket stand

Physical printing of v11 exposed a poor interaction between the **42 short pocket-following wall facets** and the adaptive tapered-panel logic. Several short faces produced narrow triangular residuals that sliced as thin, poorly supported towers and printed badly.

v12 removes that workaround rather than tuning it. The radius-3 pocket envelope is **convexified before the outer-wall offset**, filling the shallow notches between outer-ring pockets and reducing the shell to **24 longer wall faces**. The nominal outer margin increases from **3.0 mm to 3.6 mm**.

Every face can now use the same full **1.2 mm-deep / 50° tapered inset panel** with a 1 mm border. The shortest new face is about **6.78 mm**, still leaving roughly **1.92 mm of back-flat** after the taper, so the adaptive short-face depth logic and its triangular remnants are removed entirely.

Pocket count, **0° / 4° / 8° / 12°** tilt bands, 2 mm base, 55° tapered hex floor reliefs, corrected centre lead-in, effect-plate orientation, and mouth-chamfer geometry are unchanged. The cleaner shell increases CAD solid volume by about **5.3%** versus v11, an intentional trade for substantially more robust side-wall printing.

The envelope grows slightly to approximately **74.04 × 68.04 × 14.0 mm**.

## v13 — lip-edge panel 37-pocket stand

Physical evaluation of v12 showed the cleaned-up 24-face shell printing well, but the recessed wall panels still retained a visible horizontal strip between their lower edge and the flared lower lip.

v13 turns each wall recess into an **open-bottom pocket** that extends directly to the **upper edge of the lower lip at z = 2.10 mm**. The 1 mm lower border and corresponding bottom taper are removed, while the **1 mm side/top borders**, **1.2 mm recess depth**, and **50° side/top taper** remain unchanged.

A small **0.05 mm boolean overlap** carries the opening just into the lip boundary to prevent a residual shelf. All pocket, tilt, floor-relief, outer-shell, and effect-plate geometry is otherwise unchanged from v12.
 
## v14 — tiered-tilt 61-pocket stand

v14 expands the v13 radius-3 architecture by one complete hexagonal ring. The result is a **radius-4 lattice with 61 pockets**: 1 centre, 6 in ring 1, 12 in ring 2, 18 in ring 3, and **24 in the new ring 4**.

The tilt bands are now **0° / 4° / 8° / 12° / 16°**. The 16° outer ring shifts its mouth centres about **3.44 mm outward** over the 12 mm pocket depth. Even at this angle, the tilted 7 mm shaft projection leaves roughly **1.72 mm of floor-level web** on the 9 mm lattice.

The outer shell keeps the v13 convex clean-wall architecture and open-bottom lip-edge recesses. The larger body resolves to **30 clean wall faces** with the same **3.6 mm nominal margin**, **1 mm side/top panel borders**, **1.2 mm recess depth**, and **50° side/top taper**. The shortest face remains about **6.77 mm**, leaving roughly **1.91 mm of back-flat**, so no adaptive short-facet geometry is required.

Chamfer handling changes slightly for the steeper ring. The global mouth hex is rotated to **0°** against the centre shaft's **30°** orientation, giving the maximum distinct **30° phase mismatch** at the centre; tilted shaft frames then produce naturally varying apparent misalignment around the rings. The mouth remains **8.5 mm AF**, while chamfer height is fixed at **1.15 mm**. With the 16° splay, this keeps the steepest radial side of the bed-facing chamfer at about **69.9° from the build plane**, inside the agreed ~70° experimental ceiling.

The v10–v13 **2 mm base**, **1 mm-high / 55° tapered hex floor exits**, corrected centre lead-in, effect-plate orientation, softened lower lip, and open-bottom side-panel treatment are retained.

The validated envelope is approximately **93.55 × 85.22 × 14.0 mm**.

## v15 — continuous-web 61-pocket stand

A representative face-down print of v14 exposed a first-layer manufacturing failure that nominal spacing calculations had missed: the rotated/misaligned entrance geometry created local surface pinch points, some effectively collapsing to zero-width seams. v15 removed the intentional mouth/shaft rotational mismatch, aligned the shaft roll to the lattice, and introduced a new manufacturing rule: **top and bottom exposed surfaces must retain at least 1.3 mm of actual measured solid ligament after all cuts and projections**.

Pitch increased to **9.30 mm**. The exported STL measured a **1.424 mm minimum top-face web**, with the 0° / 4° / 8° / 12° / 16° tilt bands unchanged. Subsequent physical printing confirmed the corrected surface geometry and effect-plate finish.

## v16 — continuous-web 91-pocket stand

v16 added a **30-pocket 20° ring**, bringing capacity to **91 pockets**. To preserve the 1.3 mm actual-surface rule, pitch increased from 9.30 to **9.45 mm**; the exported mesh measured **1.433 mm minimum top web**. The aligned-mouth architecture, 7 mm normal-axis pocket size, 8.5 mm entrance profile, 2 mm base and 55° tapered hex exits were retained.

## v17 — continuous-web 127-pocket stand

v17 added a **36-pocket 24° ring**, giving **127 pockets total**. Pitch increased to **9.65 mm** after the prior spacing would have produced only about 1.25 mm at the tightest top-face junction. The validated model measured **1.450 mm minimum top web**.

## v18 — continuous-web 169-pocket stand

v18 added a **42-pocket 28° ring**, giving **169 pockets total**. Pitch increased to **9.90 mm** to keep the tightest exposed-surface ligament above the 1.3 mm rule. The exported mesh measured **1.472 mm minimum top web**.

## v19 — continuous-web 217-pocket stand

v19 added a **48-pocket 32° ring**, giving **217 pockets total**. Pitch increased to **10.20 mm**, producing a measured **1.493 mm minimum top web**. The steepest measured entrance-chamfer overhang remained below the 60° soft limit in the face-down print orientation.

## v20 — continuous-web 271-pocket stand

v20 added a **54-pocket 36° ring**, giving **271 pockets total** and tilt bands from 0° through 36° in 4° increments. Pitch increased to **10.55 mm**, yielding a measured **1.505 mm minimum top web**.

At this larger splay, the outer pockets approached the backs of the side recesses more closely. The nominal outer-wall margin therefore increased from 3.8 to **4.1 mm**, and the side-recess cutter reach was extended outward so the recesses remain cleanly open rather than leaving thin cover skins. Targeted side-panel sections retained at least about **1.455 mm** of remaining wall. The full envelope is approximately **221.62 × 197.46 × 14.00 mm**; a 15° in-plane rotation gives roughly **215.7 × 215.7 mm** before skirt/brim allowance.

## Common dimensions

- Functional hex pocket: **7.0 mm flat-to-flat**
- Pocket depth: **12.0 mm**
- Primary nozzle target: **0.6 mm**
- Most early/current vertical designs use a **0.6 mm / 8.2 mm AF** lead-in; v8–v10 use **1.2 mm / 8.5 mm AF**
- v10 base thickness: **2.0 mm**; earlier compact variants generally use **1.0 mm**

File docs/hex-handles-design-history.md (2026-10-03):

# Hex handles design history

The hex-handle project began from a set of previously printed driver handles with strongly sculpted bodies and later-applied surface texture. The CAD work here deliberately separates the **structural form** from that fine texture: the repository models the major ribs, collars, recesses, socket, adhesive features, and vent, while texture can be applied afterwards with a mesh modifier.

## Concept direction

The concept artwork established the target visual language:

- short, chunky workshop-tool proportions
- **five** broad longitudinal ribs
- deep planar recesses between ribs
- hard chamfers and angular transitions
- a strongly defined collar/waist region
- a segmented tail
- no dependence on fine texture for the silhouette

It also showed the functional idea of a 6.4 mm AF socket with epoxy-retention features and a tail vent.

## Discarded prototype 1 — smooth long body

The first CAD attempt captured the general waist-and-flare silhouette but was far too smooth and elongated. It lacked the concept's large structural ribs and read as a conventional rounded handle rather than the intended angular tool form.

It was not promoted into the repository version sequence.

## Discarded prototype 2 — eight-rib concept match

The second attempt added stronger fluting, collars, and a segmented tail, but still diverged from the reference in important ways:

- **eight ribs instead of five**
- rounded/filleted transitions instead of hard planar edges
- approximately 100 mm overall length
- a long section of printed handle extending beyond the metal shaft

That last point became a structural concern: with the handle printed along its axis, a long unreinforced tail could place high bending/shear load across layer lines.

It was also not promoted into the repository version sequence.

## v1 — 32 mm five-rib angular handle

The accepted design was rebuilt from scratch around the corrected constraints:

- **32 mm maximum overall length**
- a nominal **26 mm metal shaft** passing through most of the body
- exactly **5 hard-edged ribs**, 72° apart
- broad planar grip recesses
- polygonal shoulders and double collar
- only the tail tip rounded for comfort and local strength
- **6.4 mm AF** functional socket
- two outward **8.8 mm AF** epoxy reservoirs at approximately 1/3 and 2/3 depth
- continuous **2.4 mm** air/adhesive vent
- mouth-down print orientation
- a tapered internal roof instead of an abrupt horizontal bridge
- exterior slopes allowed to approach the stated **65°** printer capability rather than being artificially limited to 45°

The resulting shaft reinforces roughly **81% of the handle's length**, leaving only a short printed tail beyond the nominal metal extension.

The concept artwork and accepted V1 render are stored under `project/hex-handles/assets/`.

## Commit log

2026-10-03 Add printing notes
2026-10-03 Add v1 OpenSCAD source
    [hex_bit_stand_16.scad]
2026-10-03 Add v2 OpenSCAD source
    [hex_bit_stand_hexpattern_v2.scad]
2026-10-03 Add v3 OpenSCAD source
    [hex_bit_stand_contoured_v3.scad]
2026-10-03 Add v4 OpenSCAD source
    [hex_bit_stand_dense_51_v4.scad]
2026-10-03 Add printable STL artifacts
    [hex_bit_stand_16.stl, hex_bit_stand_contoured_v3.stl, hex_bit_stand_dense_51_v4.stl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]
2026-10-03 Add dense 13-pocket stand and soften contoured lips
    [hex_bit_stand_contoured_v3.scad, hex_bit_stand_dense_contoured_13_v6.scad]
2026-10-03 Regenerate STL artifacts
    [hex_bit_stand_contoured_v3.stl, hex_bit_stand_dense_51_v4.stl, hex_bit_stand_dense_contoured_13_v6.stl]
2026-10-03 Add outward-tilted dense 13-pocket stand
    [hex_bit_stand_outward_tilted_13_v6.scad]
2026-10-03 Make STL regeneration resilient to concurrent commits
2026-10-03 Add splayed-pocket geometry guard
    [hex_bit_stand_outward_tilted_13_v6.scad]
2026-10-03 Document v7 material-efficient 51-pocket stand
2026-10-03 Index v7 material-efficient stand
2026-10-03 Record v7 material-efficiency experiment
2026-10-03 Add v7 material-efficient 51-pocket OpenSCAD source
    [hex_bit_stand_material_efficient_51_v7.scad]
2026-10-03 Add v8 tiered-tilt 19-pocket stand
    [hex_bit_stand_tiered_tilt_19_v8.scad]
2026-10-03 Add v9 effect-plate tiered-tilt source
    [hex_bit_stand_effect_plate_19_v9.scad]
2026-10-03 Document v9 effect-plate tiered-tilt stand
2026-10-03 Index v9 effect-plate stand
2026-10-03 Document v9 effect-plate refinement
2026-10-03 Match v9 wall panels to v7 recess depth
    [hex_bit_stand_effect_plate_19_v9.scad]
2026-10-03 Add v10 tapered hex-floor effect-plate source
    [hex_bit_stand_effect_plate_19_v10.scad]
2026-10-03 Add compact five-rib hex handle project
    [hex_handle_32mm_5rib_v1.scad]
2026-10-03 Generate hex handle V1 STL
    [hex_handle_32mm_5rib_v1.stl]
2026-10-04 Add v11 37-pocket tiered-tilt source
    [hex_bit_stand_tiered_tilt_37_v11.scad]
2026-10-04 Add v12 clean-wall 37-pocket source
    [hex_bit_stand_tiered_tilt_37_v12.scad]
2026-10-04 Add v13 lip-edge wall panels
    [hex_bit_stand_tiered_tilt_37_v13.scad]
2026-10-04 Add v14 61-pocket tiered-tilt source
    [hex_bit_stand_tiered_tilt_61_v14.scad]
2026-10-04 Add v15 aligned 61-pocket stand and enforce measured 1.3 mm surface webs
    [hex_bit_stand_continuous_web_61_v15.scad]
2026-10-07 Add v16 91-pocket continuous-web source
    [hex_bit_stand_continuous_web_91_v16.scad]
2026-10-07 Add v17 127-pocket continuous-web source
    [hex_bit_stand_continuous_web_127_v17.scad]
2026-10-07 Add v18 169-pocket continuous-web source
    [hex_bit_stand_continuous_web_169_v18.scad]
2026-10-07 Add v19 217-pocket continuous-web source
    [hex_bit_stand_continuous_web_217_v19.scad]
2026-10-07 Add v20 271-pocket continuous-web source
    [hex_bit_stand_continuous_web_271_v20.scad]
2026-10-07 Avoid STL regeneration conflicts during publication
2026-10-07 Trigger canonical STL regeneration for published continuous-web variants
    [hex_bit_stand_continuous_web_271_v20.scad]
2026-10-08 Link complete v15–v20 bundles and harmonize project records (#2)
    Preserve the original v15–v20 bundles on their verified checkpoint branch and link the complete matched toolsets, reports, exports and provenance from the existing project READMEs. Reconcile the hist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
2026-10-11 Add SweepHex 120/92/80/60 XL fan guards (#4)
    Publish validated 120 mm, 92 mm, 80 mm and 60 mm SweepHex XL variants with shared parametric source, printable STL/3MF files, DXF profiles, geometry reports and family indexing.
